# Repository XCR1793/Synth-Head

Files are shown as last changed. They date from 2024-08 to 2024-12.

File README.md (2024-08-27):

# Synth Head
To create an open source suit which can be worn by an individual and customised to their will. It also must be constructed in such a way that an average human could build it within a reasonable budget and time. The suit must be modular whilst remaining safe for the user to operate. The software must be easy to configure for any individual and has capability to modify without the need to always reflashing its firmware. The project was created according to this standard however, it has evolved over time to be more of a testing ground for sensors and other features of the like as I will continue this along with other projects I have due to compatibility.

DX.3

## Overview
This project is always in the works and will be updated. Although regular updates are not possible due to me still being in uni, I will do what I can. This repo is basically a better version of the other repo and a true migration as the old one due to its structure. The reason for it being a new repo rather then just a fix is cause the title changed so the old link wouldn't have worked anyway. The current design is DX which stands for Design 10 as it is the 10th time the base shape has changed, the .3 at the end is an iterator for which version were on.

### Features
* <strong style='color: #99ccff;'>Vacuum Formed Visor</strong> allows the user to see out of a clear shell rather then the previous mesh version which caused chromatic abberation, preventing the true colours of the display from emiting through the visor properly.
* <strong style='color: #99ccff;'>Detachable Substructure</strong> which conformes to the visor ridge provides an easy to modify platform to which different displays, sensors and other modules.
* <strong style='color: #99ccff;'>Builtin Head Restraint</strong> was designed to hold in an average head with relatively high pressure, although the pressure seems like it cause pain, the addition of a foam pad mitigates this and is actually comfortable to wear.
* <strong style='color: #99ccff;'>Silent Slim Jaw Mount</strong> of around 6mm in total thickness is directly integrated to the shell.
* <strong style='color: #99ccff;'>Snoot Sensors</strong> All of the sensors and modules are attached directly into the detachable substructure and can easily be replaced and upgraded as needed, many of which includes: Boop detection, snoot holding detection & IMUs.
* <strong style='color: #99ccff;'>Ventillation</strong> is key to an alive and well user, there are 2 fans located below the tongue which negatively ventillates the user.

### In the works
* The visor edge and mating surface will be changed due to it currently resulting in an uneven edge to edge connection.
* The builtin head restraint will also be upgraded, although the system works it is not the best designed as it is currently difficult to put the pins in place.
* Electronics & other cabling will be hidden in the final release as it is not compact due to the Rushed version built for speed and prototyping rather then stability.
* ARCOS migration is still under play, the entire library is basically being rewritten slowly so it runs faster with more features. The library is currently not accessable as it is privated but it will be released with the release of the synth head 10.3.
* <strong style='color: #ffb3ff;'>Feature Inclusion:</strong> Cable management
* <strong style='color: #ffb3ff;'>Feature Inclusion:</strong> Visor Edge Alignment Upgrade
* <strong style='color: #ffb3ff;'>Feature Inclusion:</strong> Ventillation Upgrade
* <strong style='color: #ffb3ff;'>Feature Inclusion:</strong> Jaw Mount Upgrade (Attached to head restraint)
* <strong style='color: #ffb3ff;'>Feature Inclusion:</strong> Lighter Frame
* <strong style='color: #ffb3ff;'>Feature Inclusion:</strong> Custom PCB (Control Board, Power & Sensors)

### Roadmap
* <strong style='color: #99ff99;'>Milestone:</strong> [Synth Head DX](/Archives/DX/README.md)
* <strong style='color: #99ff99;'>Milestone:</strong> [Synth Head DX.1](/Archives/DX.1/README.md)
* <strong style='color: #99ff99;'>Milestone:</strong> [Synth Head DX.2 Rushed](/Archives/DX.2/README.md)
* <strong style='color: #99ff99;'>Milestone:</strong> [Synth Head DX.3 Rushed](/Archives/DX.3/README.md)
* <strong style='color: #99ff99;'>Milestone:</strong> Properly Structured Github

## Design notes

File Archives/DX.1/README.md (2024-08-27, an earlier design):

# Synth Head DX.1
Building off of the DX base, many more components were added. This version of the DX series was to brainstorm, test and prototype if the shell worked IRL along with with features could be theoretically added. I stayed in this version for a while when developing the physical design and concidering alternative restraint mechanisms. The [manifesto](/README.md#synth-head) when constructing this remained. Although this version does have a physical build to it, <strong style='color: #ff0000;'>IT IS NOT RECOMMENDED</strong> that you construct this without your modifications due to some known design issues.

## Known Issues
* Neck Plate Attachment to head is missing as the plates were an after thought.
* Neck Plate Attachment to each other is also missing as the plates were designed independantly of each other and near the end of the version's use.
* Head Restraint not providing enough pressure was determined after construction as the realisation that there was no tensioning mechanism other then just manually pulling the steel zip tie.
* No way to properly attach the tongue as this was designed during construction.
* Neck Plate Tensioning is lacking as the rubber bands that were used barely had enough strength to prop themselves up.
* Unconfortable Jaw Joint design which was only detected after constructing and during the testing stages.

## File Structure
<strong style='color: #bb99ff;'>XCR Head DX.1.f3d</strong> : A fusion 360 file for the main project where the entirity of DX.1 was designed.

<strong style='color: #bb99ff;'>XCR Head DX.1.step</strong> : A step file version incase you dont have fusion 360 to open the main project.

<strong style='color: #bb99ff;'>Rubber Holder V3.step</strong> : A step file of the rubber band holder reference.

<strong style='color: #bb99ff;'>Subsurface Jaw Joint V3.step</strong> : A step file of the jaw joint v3 mechanism.

<strong style='color: #bb99ff;'>Ziptie Release & Back Brace.step</strong> : A step file of the steel cable tie head restraint assembly.

<strong style='color: #bb99ff;'>Visor Mesh.step</strong> : A step file for the Mesh Visor addon incase you cant vacuum form your own visor.

<strong style='color: #bb99ff;'>DX Visor Buck.f3d</strong> : A f3d file for the visor buck to vacuum form.

<strong style='color: #bb99ff;'>DX Visor Buck.step</strong> : A step file for the visor buck to vacuum form incase you dont have fusion 360.

## Features & Design Considerations
### DX
All features from the DX base design are included except the Jaw Joint and a modification to the head restraint.

### Jaw Joint Upgrade
The jaw hinge mechanism was upgraded from V2 to V3 which allows a slimmer mating surface which connects the jaw to the shell. This new version does not require a teflon tube to be inserted to lock the hinge into place, rather it is a press and turn system where the joint is designed to be integrated below the surface of the shell rather then on top. This allows the upgrade to sit more flush within the shell.

### Foam Mount for Head Restraint
As hotglue is not always available to the user, an inset slot was designed to grip the foam on its way in rather than with any other adhesives, preventing the foam from being destroyed due to hotglue and granting the user to easily change it out.

### Steel Cable Tie Head Restraint
As the base design offered no tensioning or size adjustment mechanism, a slidable adjuster was created via leveraging the use of a steel cable tie. Slight modifications to the actual cable tie sliding system was required to allow the cable tie to actually unlock.

### Steel Cable Tie Neck Plate Mounts
The springy ness of the steel cable tie was also experimented here by attaching the neck plates to them which automatically averaged their positions like a spline, which proved incredibly useful as the rubber bands on their own could not do the job.

### Slottable Top Maw Plate
An upgrade to the maw plate also was required however, it still did required the user to tack weld the piece into place as there wasn't any system that prevent it from just popping back out.

### Jaw Rubber Band Tensioning
Using the V3 rubber band mount proved to be a worthy upgrade as it prevented the sharp edges of the previous design from scratching the user during its motion. It is required for the jaw to function as there is no mechanism that prevents the jaw from slacking open.

### TPU Neck Plate Mounts
In addition to the steel cable tie mounts for the neck plates, a tpu version was also tested. This design allowed fixed equal spacing between the scales plates whilst also being flexible enough to bend to the user's movements.

### Mesh Visor Addon
If you dont have access to a vacuum former then fret not, I have also provided a mesh version of the visor which you can 3D print or cut out that should confirm roughly to the shape of the original visor.

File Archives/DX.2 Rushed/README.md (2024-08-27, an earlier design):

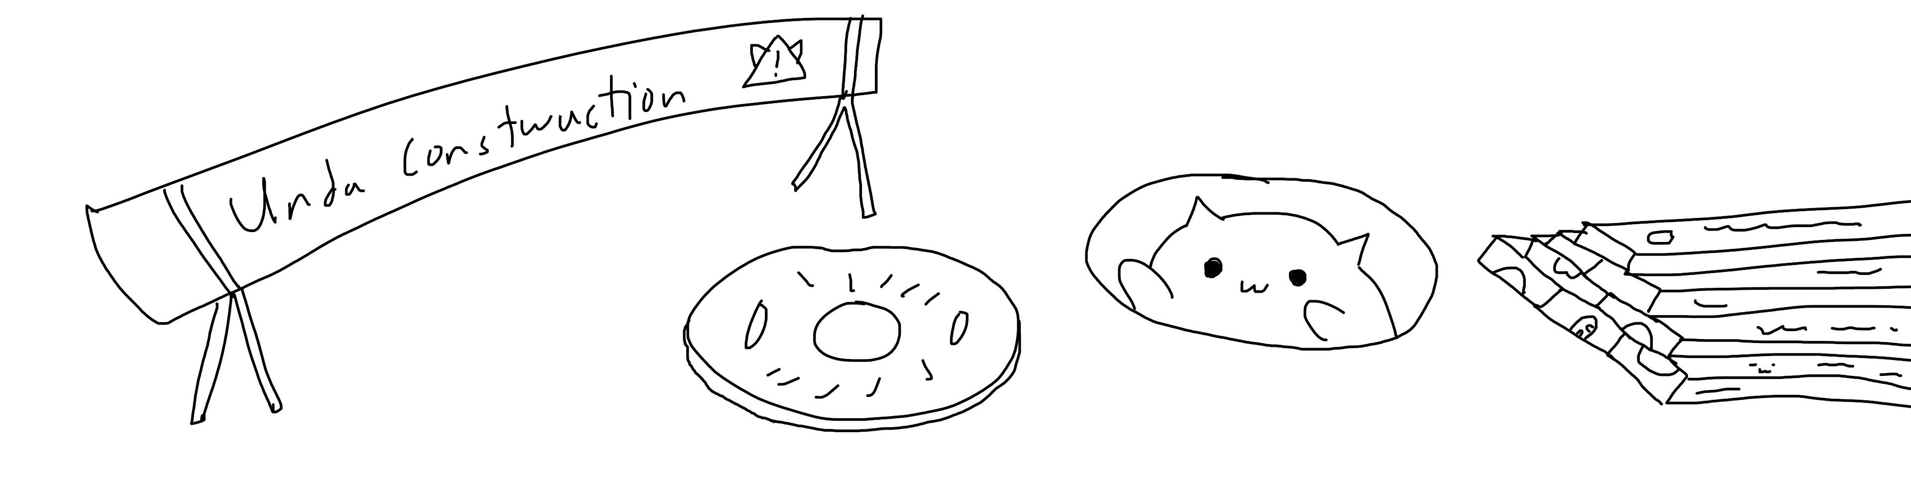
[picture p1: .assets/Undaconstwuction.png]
UnderConstruction


# DX.2 Rushed
Rushed is a modifier that is placed after a project name if I am under a heavy time constraint such as 2-3 weeks to construct one from scratch. 

## Knows Issues

## File Structure
<strong style='color: #bb99ff;'></strong>

## Features & Design Considerations
### <strong style='color: #ff9999;'>Hardware:</strong> DX
All features from the DX base design are included except the Jaw Joint and a modification to the head restraint.

### <strong style='color: #ff9999;'>Hardware:</strong> Large Powerbank Holder
A strong partial case designed to hold a heavy duty powerbank which also doubles as a balancing mechanism to prevent the forward torque caused by unequal weight distrobution of the synth head.

### <strong style='color: #ff9999;'>Hardware:</strong> Head Restraint
The Restraint changed 

### <strong style='color: #ff9999;'>Hardware:</strong> Modified Jaw Joint

### <strong style='color: #ff9999;'>Hardware:</strong> Maw Top Plate Mounting

### <strong style='color: #ff9999;'>Hardware:</strong> Magnetic Visor Mount

### <strong style='color: #ff9999;'>Hardware:</strong> Electronics Mounts

### <strong style='color: #99ff99;'>Electronics:</strong> IR User Detection

### <strong style='color: #99ff99;'>Electronics:</strong> Menu Buttons

### <strong style='color: #99ff99;'>Electronics:</strong> ESP32 Hall Effect

### <strong style='color: #99ff99;'>Electronics:</strong> Dual ESP32

### <strong style='color: #99ff99;'>Electronics:</strong> IMU

### <strong style='color: #99ff99;'>Electronics:</strong> Fan

### <strong style='color: #99ff99;'>Electronics:</strong> HUB75 LED Matrix P3

### <strong style='color: #99ff99;'>Electronics:</strong> LED Strips

### <strong style='color: #99ffff;'>Software:</strong> Boot Screen

### <strong style='color: #99ffff;'>Software:</strong> LED Display

### <strong style='color: #99ffff;'>Software:</strong> Eye Wobble

### <strong style='color: #99ffff;'>Software:</strong> RGB Shader

### <strong style='color: #99ffff;'>Software:</strong> User Detection

### <strong style='color: #99ffff;'>Software:</strong> Visor Detection

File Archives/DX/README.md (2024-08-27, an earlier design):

# Synth Head DX
This is the first the 10th design line up, although the physical architecture is simple it layed the foundation for the other versions to be built on. <strong style='color: #ff0000;'>DO NOT FABRICATE AS IS</strong> as the shape and overall dimentions were the priority when designing this base, this version is more so to be used as an easily modifiable platform which anyone can take and customise. This version has not been created IRL as like mentioned before it was more designed for its shape.

## File Structure
<strong style='color: #bb99ff;'>XCR Head DX.f3d</strong> : The fusion 360 file which has everything that was used for the design.

<strong style='color: #bb99ff;'>XCR Head DX.step</strong> : A step file export from fusion 360 if you dont have the program.

## Features & Design Considerations
### Vacuum Formed Visor
The visor contour is designed in such a way, where the visor can rotate outwards rather then relying on the flexibility of the material to snap in place. This prevents the visor from deforming which allows substructures and other features to reliably attach to the visor material. Although a complex shape, it is relatively easy to vacuum form.

<!-- ![DX Visor](../../.assets/DX%20Visor.png) -->

### Visor Ridge
The visor ridge of the shell was designed to "catch" the visor on the way on so that it will always be inline with the shell to leave a near seamless smooth finish. The design process is very simple, consisting of a few offsets and is proceedurly generated allowing any visor shape to fit in this way.
 
### Teeth Rotation
The teeth of the outer shell are rotated slightly along with the jaw being slightly indented. This shape prevents the jaw and the shell from colliding when it moves.

### Head Restraint
This prevents the user's head from moving within the synth head, although it is only a rudamentory design, it was created to have foam hotglued into place. The front and back pieces along with the side shell, locks the user's head in translational movement. Rotational movement is only restrained via pressure which isn't the best method as it doesnt take advantage of the oval shape of the human head, which can be used to geometrically lock the rotation properly like a bike helmet.

### Jaw Joint
The joint mechanism used here was the most tested version at that time which consists of a slot which the jaw can lock into via a teflon pin. This was later depreciated for a better design which allowed the jaw to lock into place via pressing it in and rotating it.

### Maw Top Plate
To mount components such as the display, a top plate was added to do just that. This version just showed whether or not such a design would be aesthetically pleasing along with physically advantages.

### Nose Holes
Holes in the shell served 2 purposes, the first is for it to be accurate to the species however the second reason was for ventillation. Although it doesn't do much, it was design to be enough for air to circulate outwards and the visor to not fog up.

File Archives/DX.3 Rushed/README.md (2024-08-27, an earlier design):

UnderConstruction

# DX.3 Rushed

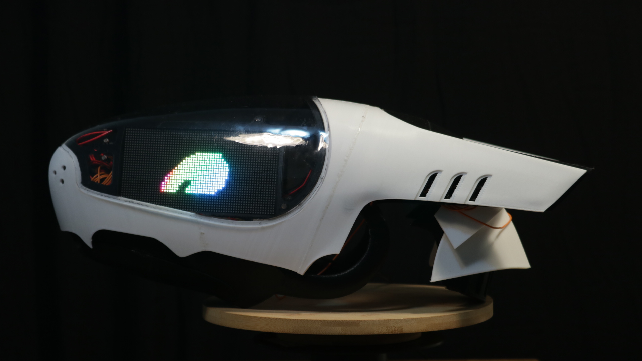
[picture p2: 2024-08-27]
.assets/DX.3 Rushed Side.JPG

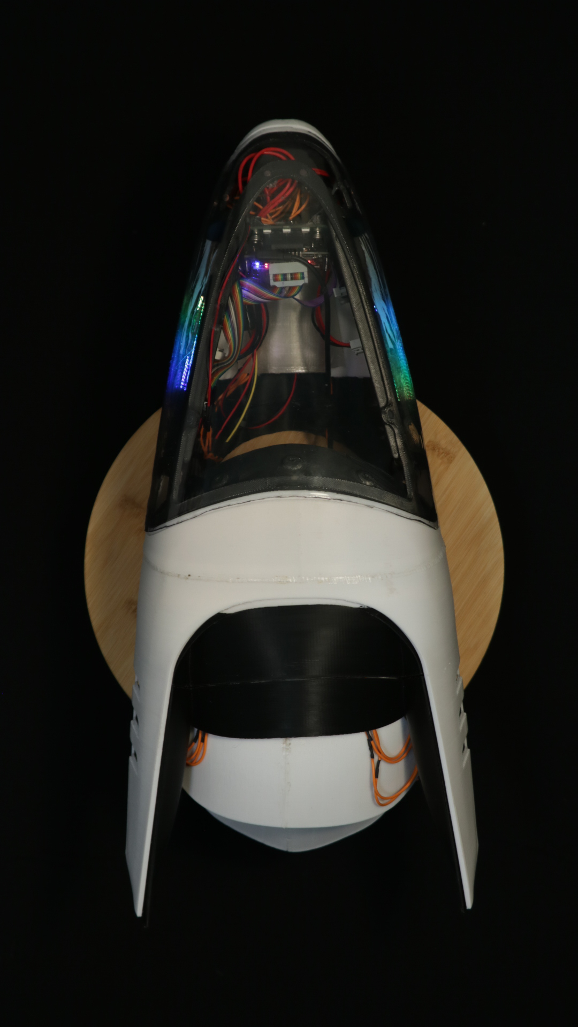
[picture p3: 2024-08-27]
.assets/DX.3 Rushed Top.JPG

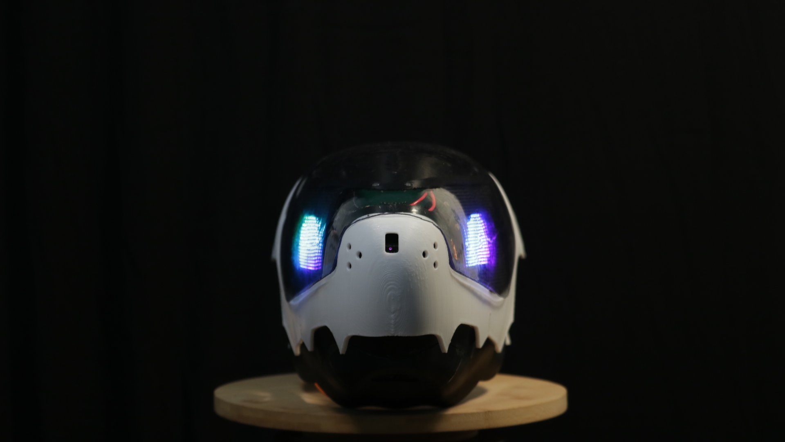
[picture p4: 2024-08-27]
.assets/DX.3 Rushed Front.JPG

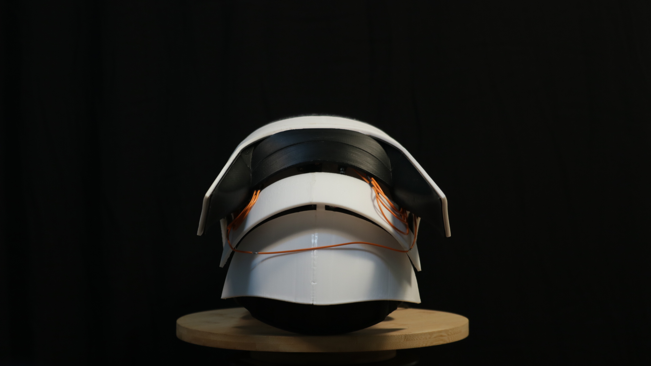
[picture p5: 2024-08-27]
.assets/DX.3 Rushed Back.JPG

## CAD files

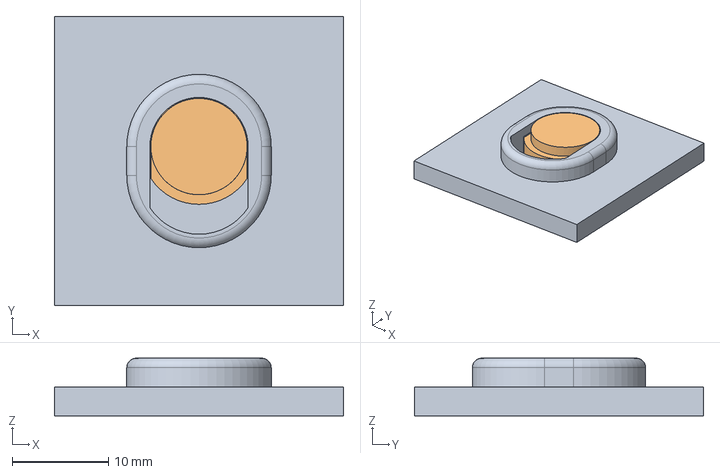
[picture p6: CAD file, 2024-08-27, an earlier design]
Archives/DX.1/Subsurface Jaw Joint V3.step
30.0 x 30.0 x 6.00 mm

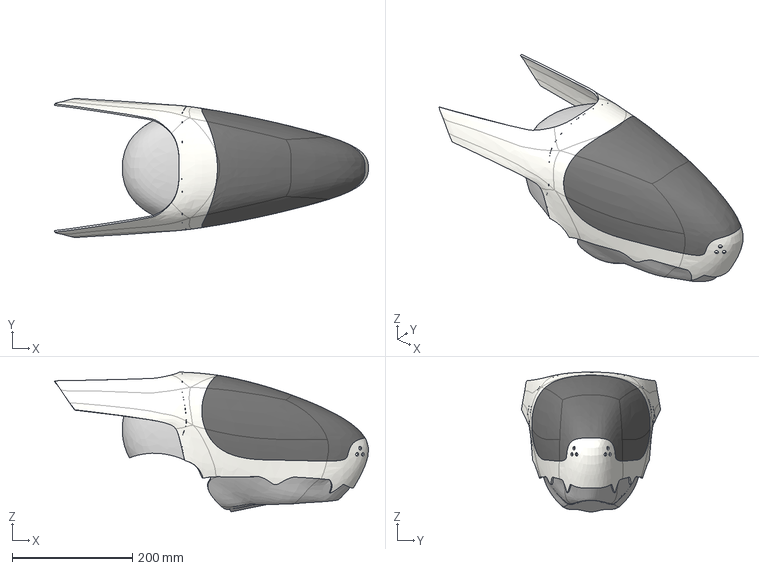
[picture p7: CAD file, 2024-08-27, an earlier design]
Archives/DX/XCR Head DX.step
522.6 x 231.6 x 232.7 mm

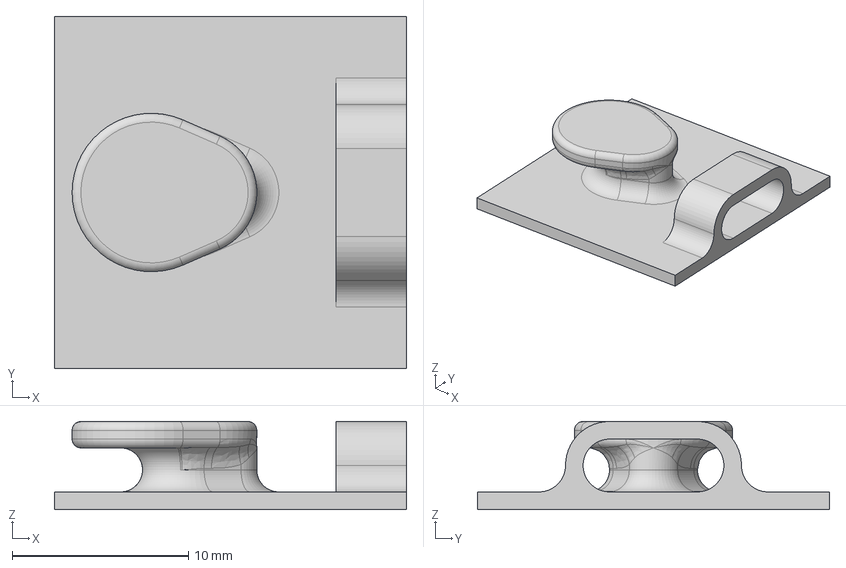
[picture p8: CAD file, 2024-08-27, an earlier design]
Archives/DX.1/Rubber Holder V3.step
20.0 x 20.0 x 5.00 mm

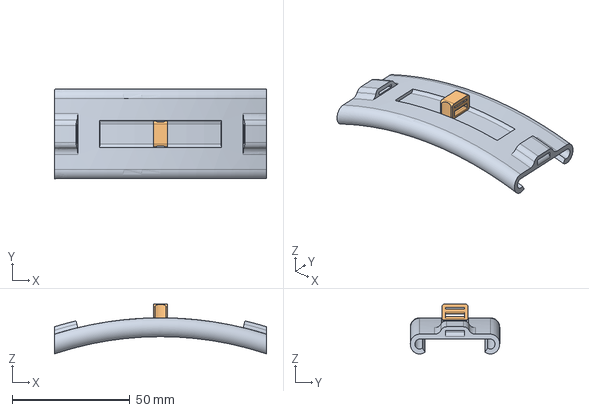
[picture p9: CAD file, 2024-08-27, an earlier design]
Archives/DX.1/Ziptie Release & Back Brace.step
90.0 x 38.0 x 21.2 mm

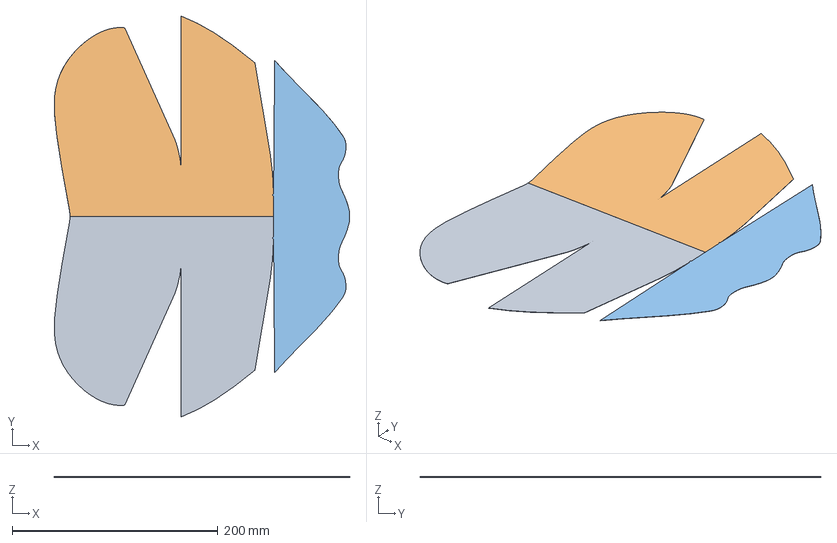
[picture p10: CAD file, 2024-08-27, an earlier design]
Archives/DX.1/Visor Mesh.step
287.4 x 390.0 x 0.2 mm

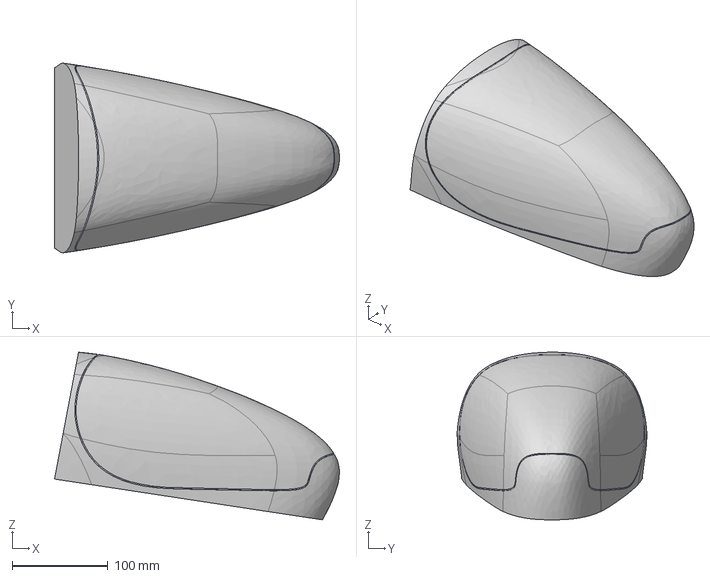
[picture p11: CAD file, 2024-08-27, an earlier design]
Archives/DX.1/DX Visor Buck.step
298.2 x 198.6 x 175.5 mm

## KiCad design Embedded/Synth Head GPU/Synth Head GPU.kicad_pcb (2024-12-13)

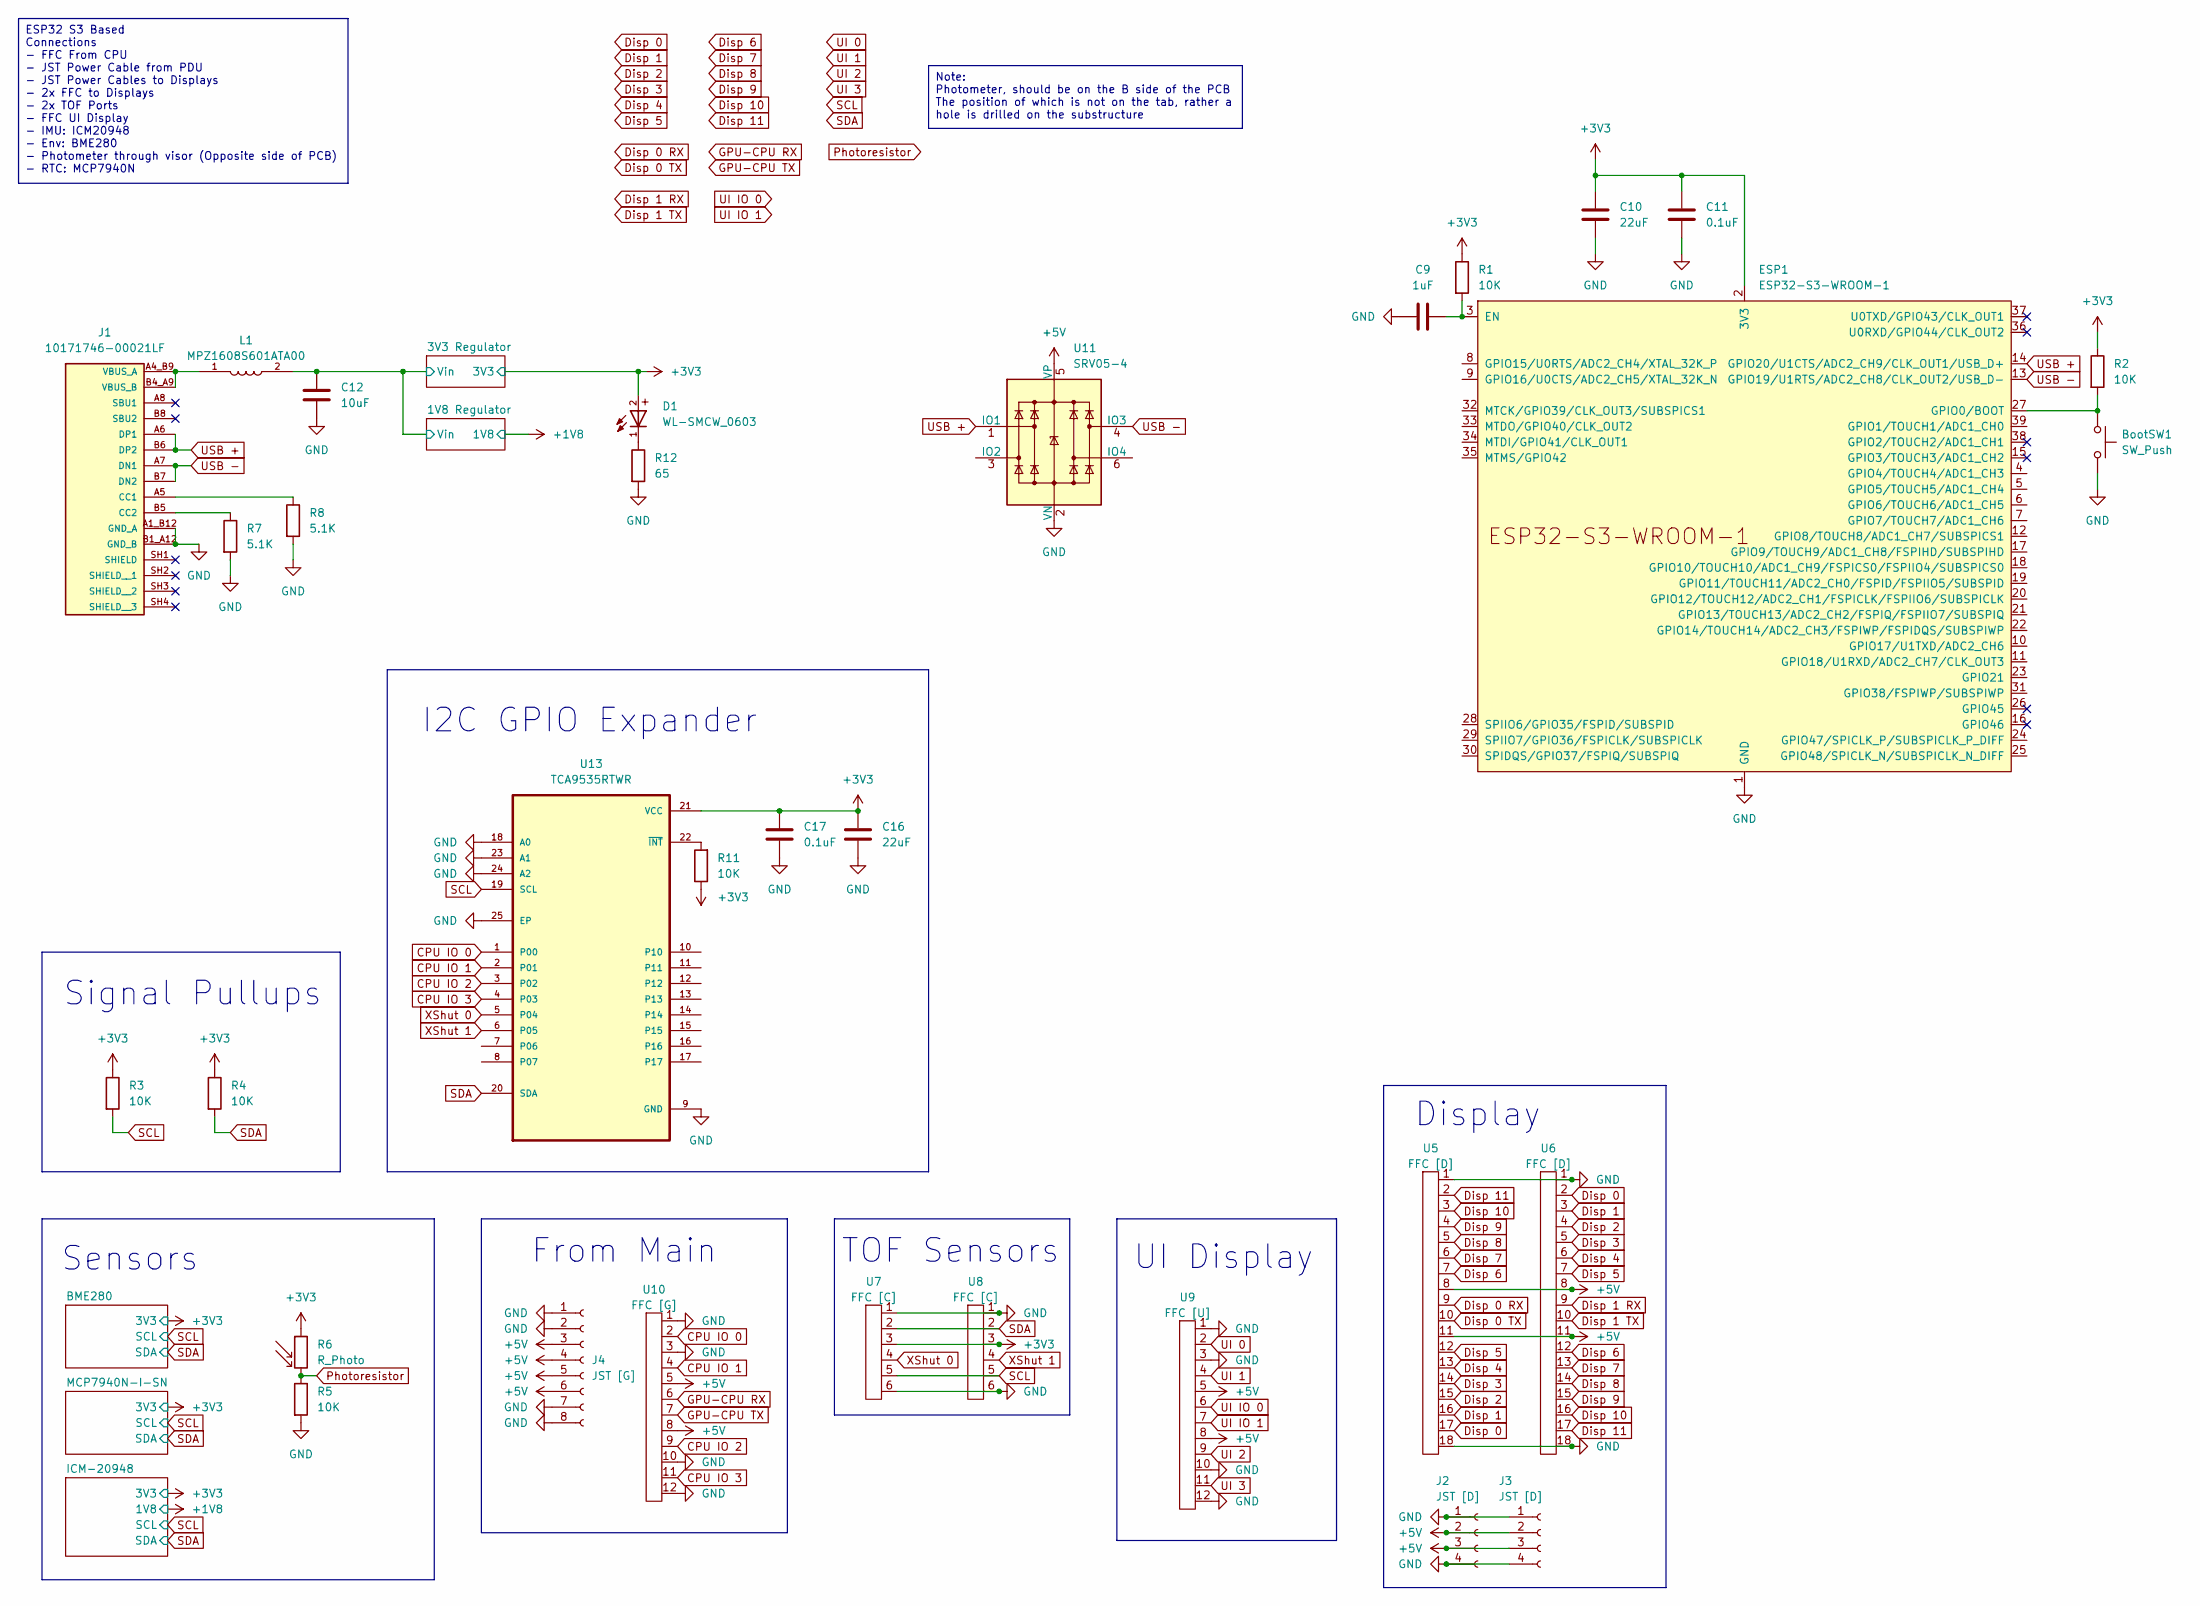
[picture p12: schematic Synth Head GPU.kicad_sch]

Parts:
BootSW1: SW_Push; Button-R-667843
C9: 1uF; C_0603_1608Metric
C10, C16: 22uF; C_0603_1608Metric_Pad1.08x0.95mm_HandSolder
C11, C17: 0.1uF; C_0603_1608Metric
C12: 10uF; C_0603_1608Metric
D1: WL-SMCW_0603
ESP1: ESP32-S3-WROOM-1; ESP32-S3-WROOM-1U
J1: 10171746-00021LF; AMPHENOL_10171746-00021LF; PARTREV A
J2, J3: JST [D]; Molex_PicoBlade_53048-0410_1x04_P1.25mm_Horizontal
J4: JST [G]; PinHeader_1x08_P2.54mm_Horizontal
L1: MPZ1608S601ATA00; INDC1608X95N
R1, R2, R11: 10K; R_0603_1608Metric
R3, R4, R5: 10K; R_0603_1608Metric_Pad0.98x0.95mm_HandSolder
R6: R_Photo; Photoresistor Aliexpress
R7, R8: 5.1K; R_0603_1608Metric
R12: 65; R_0603_1608Metric_Pad0.98x0.95mm_HandSolder
U5, U6: FFC [D]; FFC Aliexpress 0.5mm 18P
U7, U8: FFC [C]; FFC Aliexpress 0.5mm 6P
U9: FFC [U]; FFC Aliexpress 0.5mm 12P
U10: FFC [G]; FFC Aliexpress 0.5mm 12P
U11: SRV05-4; SOT-23-6
U13: TCA9535RTWR; QFN50P400X400X80-25N

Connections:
+3V3: C10.1, C11.1, C16.1, C17.1, D1.2, ESP1.2 (3V3), R1.1, R2.1, R3.1, R4.1, R6.1, R11.1, U7.3, U8.3, U13.21 (VCC); also elsewhere on the board
CPU IO 0: U10.2, U13.1 (P00)
CPU IO 1: U10.4, U13.2 (P01)
CPU IO 2: U10.9, U13.3 (P02)
CPU IO 3: U10.11, U13.4 (P03)
Disp 0: U5.17, U6.2
Disp 0 RX: U5.9
Disp 0 TX: U5.10
Disp 1: U5.16, U6.3
Disp 1 RX: U6.9
Disp 1 TX: U6.10
Disp 2: U5.15, U6.4
Disp 3: U5.14, U6.5
Disp 4: U5.13, U6.6
Disp 5: U5.12, U6.7
Disp 6: U5.7, U6.12
Disp 7: U5.6, U6.13
Disp 8: U5.5, U6.14
Disp 9: U5.4, U6.15
Disp 10: U5.3, U6.16
Disp 11: U5.2, U6.17
GND: BootSW1.2, C9.1, C10.2, C11.2, C12.2, C16.2, C17.2, ESP1.1 (GND), ESP1.40 (GND), ESP1.41 (GND), J1.A1_B12 (GND_A), J1.B1_A12 (GND_B), J2.1, J2.4, J3.1, J3.4, J4.1, J4.2, J4.7, J4.8, R5.2, R7.2, R8.2, R12.2, U5.1, U5.18, U6.1, U6.18, U7.1, U7.6, U8.1, U8.6, U9.1, U9.3, U9.10, U9.12, U10.1, U10.3, U10.10, U10.12, U11.2 (VN), U13.9 (GND), U13.18 (A0), U13.23 (A1), U13.24 (A2), U13.25 (EP); also elsewhere on the board
GPU-CPU RX: U10.6
GPU-CPU TX: U10.7
unnamed: D1.1, R12.1
unnamed: C9.2, ESP1.3 (EN), R1.2
unnamed: BootSW1.1, ESP1.27 (GPIO0/BOOT), R2.2
unnamed: J1.A5 (CC1), R8.1
unnamed: J1.B5 (CC2), R7.1
unnamed: R11.2, U13.22 (~INT)
Photoresistor: R5.1, R6.2
SCL: R3.2, U7.5, U8.5, U13.19 (SCL); also elsewhere on the board
SDA: R4.2, U7.2, U8.2, U13.20 (SDA); also elsewhere on the board
UI 0: U9.2
UI 1: U9.4
UI 2: U9.9
UI 3: U9.11
UI IO 0: U9.6
UI IO 1: U9.7
USB +: ESP1.14 (GPIO20/U1CTS/ADC2_CH9/CLK_OUT1/USB_D+), J1.A6 (DP1), J1.B6 (DP2), U11.1 (IO1)
USB -: ESP1.13 (GPIO19/U1RTS/ADC2_CH8/CLK_OUT2/USB_D-), J1.A7 (DN1), J1.B7 (DN2), U11.4 (IO3)
XShut 0: U7.4, U13.5 (P04)
XShut 1: U8.4, U13.6 (P05)

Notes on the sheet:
ESP32 S3 Based Connections - FFC From CPU - JST Power Cable from PDU - JST Power Cables to Displays - 2x FFC to Displays - 2x TOF Ports - FFC UI Display - IMU: ICM20948 - Env: BME280 - Photometer through visor (Opposite side of PCB) - RTC: MCP7940N
Note: Photometer, should be on the B side of the PCB The position of which is not on the tab, rather a hole is drilled on the substructure
Signal Pullups
I2C GPIO Expander
TOF Sensors
From Main
Display
UI Display
Sensors

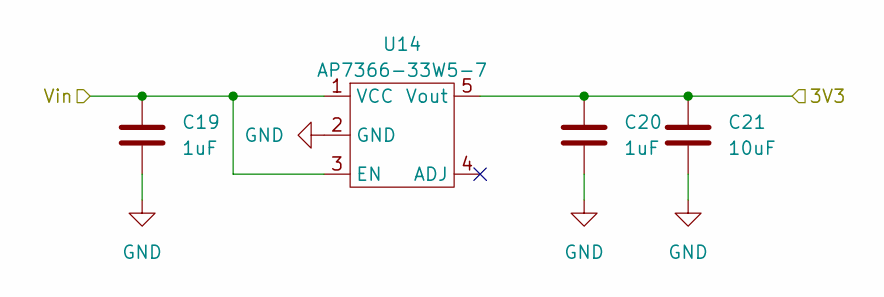
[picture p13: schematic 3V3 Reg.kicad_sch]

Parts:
C19, C20: 1uF; R_0603_1608Metric
C21: 10uF; C_0603_1608Metric
U14: AP7366-33W5-7; AP7366

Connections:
+3V3: C20.1, C21.1, U14.5 (Vout); also elsewhere on the board
GND: C19.2, C20.2, C21.2, U14.2 (GND); also elsewhere on the board

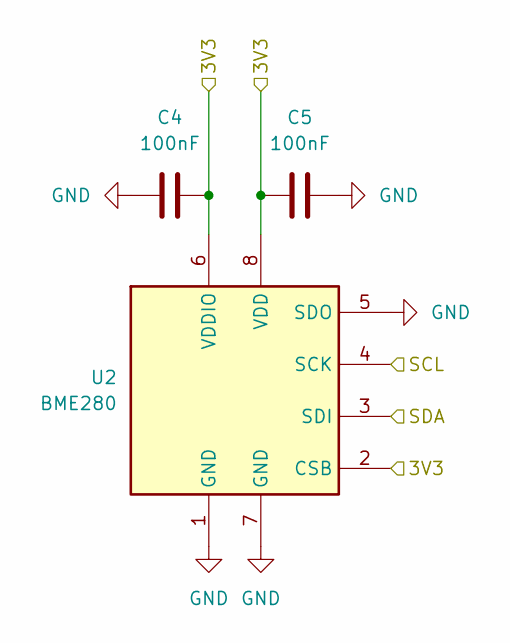
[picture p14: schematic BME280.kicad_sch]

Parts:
C4, C5: 100nF; C_0603_1608Metric_Pad1.08x0.95mm_HandSolder
U2: BME280; Bosch_LGA-8_2.5x2.5mm_P0.65mm_ClockwisePinNumbering

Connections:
+3V3: C4.2, C5.1, U2.2 (CSB), U2.6 (VDDIO), U2.8 (VDD); also elsewhere on the board
GND: C4.1, C5.2, U2.1 (GND), U2.5 (SDO), U2.7 (GND); also elsewhere on the board
SCL: U2.4 (SCK); also elsewhere on the board
SDA: U2.3 (SDI); also elsewhere on the board

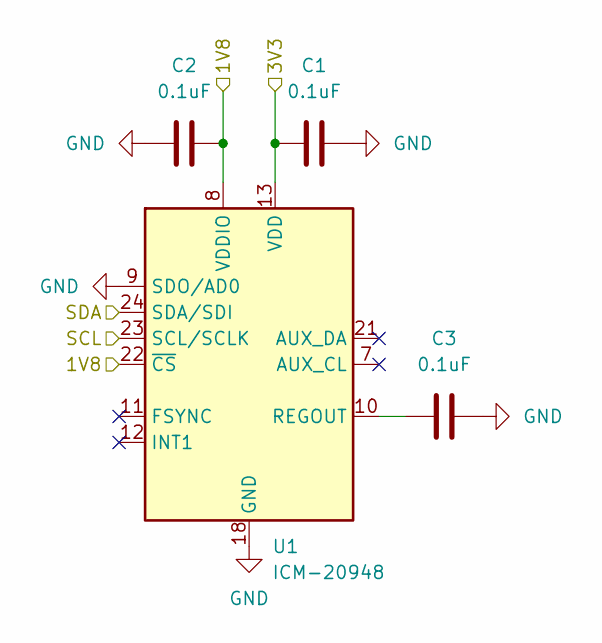
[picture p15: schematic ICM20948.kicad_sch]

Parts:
C1, C2, C3: 0.1uF; C_0603_1608Metric_Pad1.08x0.95mm_HandSolder
U1: ICM-20948; InvenSense_QFN-24_3x3mm_P0.4mm

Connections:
+1V8: C2.2, U1.8 (VDDIO), U1.22 (~CS); also elsewhere on the board
+3V3: C1.1, U1.13 (VDD); also elsewhere on the board
GND: C1.2, C2.1, C3.2, U1.9 (SDO/AD0), U1.18 (GND), U1.20 (GND); also elsewhere on the board
unnamed: C3.1, U1.10 (REGOUT)
SCL: U1.23 (SCL/SCLK); also elsewhere on the board
SDA: U1.24 (SDA/SDI); also elsewhere on the board

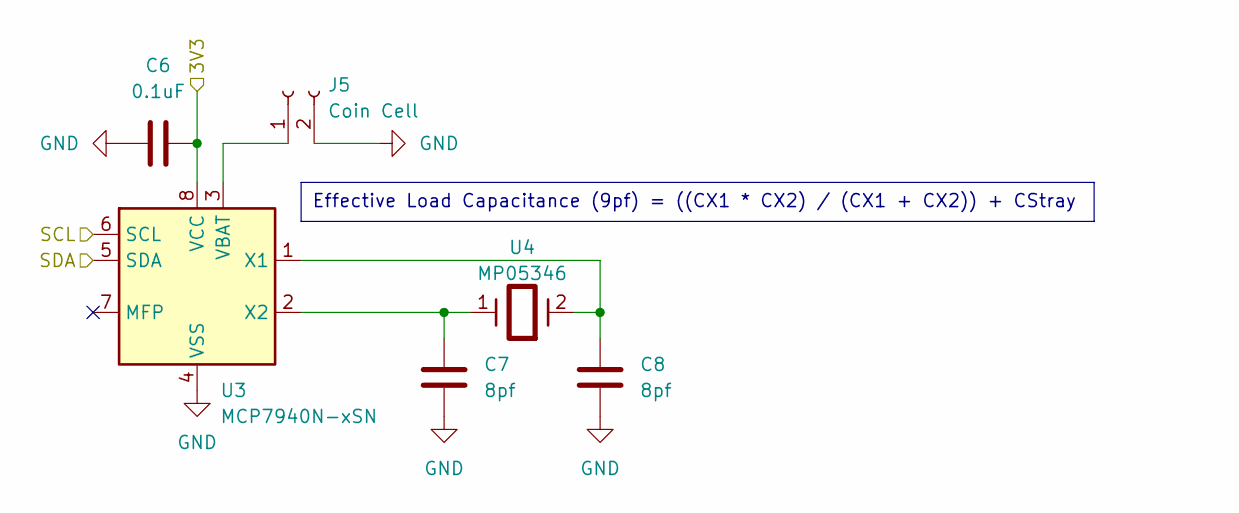
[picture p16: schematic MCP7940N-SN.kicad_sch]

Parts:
C6: 0.1uF; C_0603_1608Metric_Pad1.08x0.95mm_HandSolder
C7, C8: 8pf; C_0603_1608Metric_Pad1.08x0.95mm_HandSolder
J5: Coin Cell; PinHeader_1x02_P2.54mm_Vertical
U3: MCP7940N-xSN; SOIC-8_3.9x4.9mm_P1.27mm
U4: MP05346

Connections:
+3V3: C6.2, U3.8 (VCC); also elsewhere on the board
GND: C6.1, C7.2, C8.2, J5.2, U3.4 (VSS); also elsewhere on the board
unnamed: J5.1, U3.3 (VBAT)
unnamed: C8.1, U3.1 (X1), U4.2
unnamed: C7.1, U3.2 (X2), U4.1
SCL: U3.6 (SCL); also elsewhere on the board
SDA: U3.5 (SDA); also elsewhere on the board

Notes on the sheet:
Effective Load Capacitance (9pf) = ((CX1 * CX2) / (CX1 + CX2)) + CStray

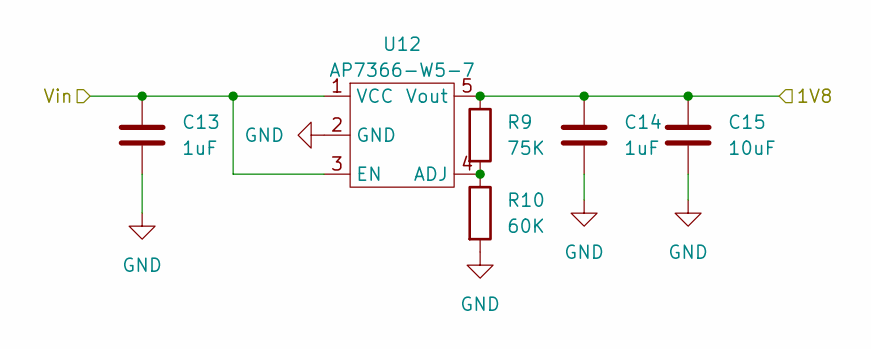
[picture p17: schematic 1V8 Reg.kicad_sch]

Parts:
C13, C14: 1uF; R_0603_1608Metric
C15: 10uF; C_0603_1608Metric
R9: 75K; R_0603_1608Metric
R10: 60K; R_0603_1608Metric
U12: AP7366-W5-7; AP7366

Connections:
+1V8: C14.1, C15.1, R9.1, U12.5 (Vout); also elsewhere on the board
GND: C13.2, C14.2, C15.2, R10.2, U12.2 (GND); also elsewhere on the board
unnamed: R9.2, R10.1, U12.4 (ADJ)

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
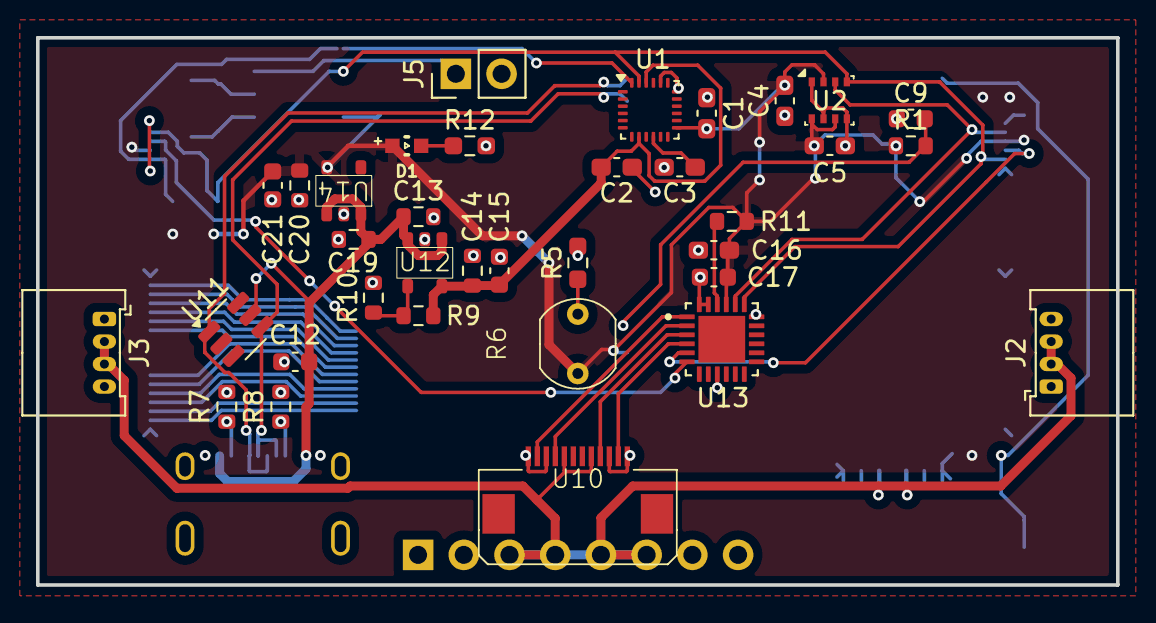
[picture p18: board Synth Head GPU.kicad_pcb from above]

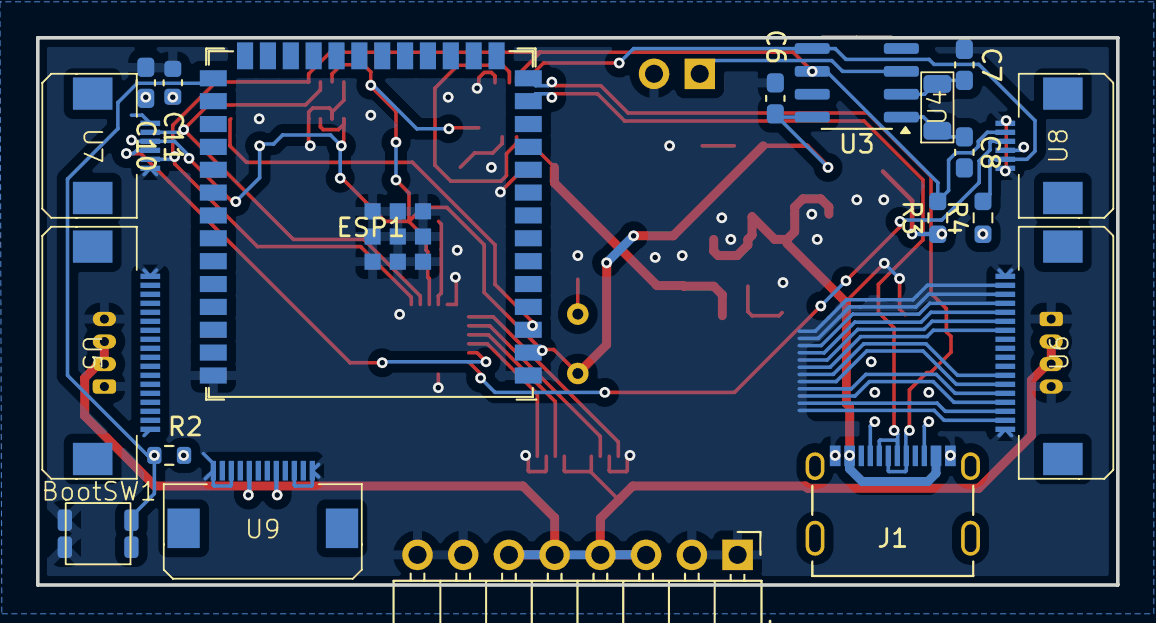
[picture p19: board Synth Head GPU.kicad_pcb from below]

Board: 2 copper layers, 60.0 x 30.4 mm, 54 parts (19 on the bottom side), 38 nets.

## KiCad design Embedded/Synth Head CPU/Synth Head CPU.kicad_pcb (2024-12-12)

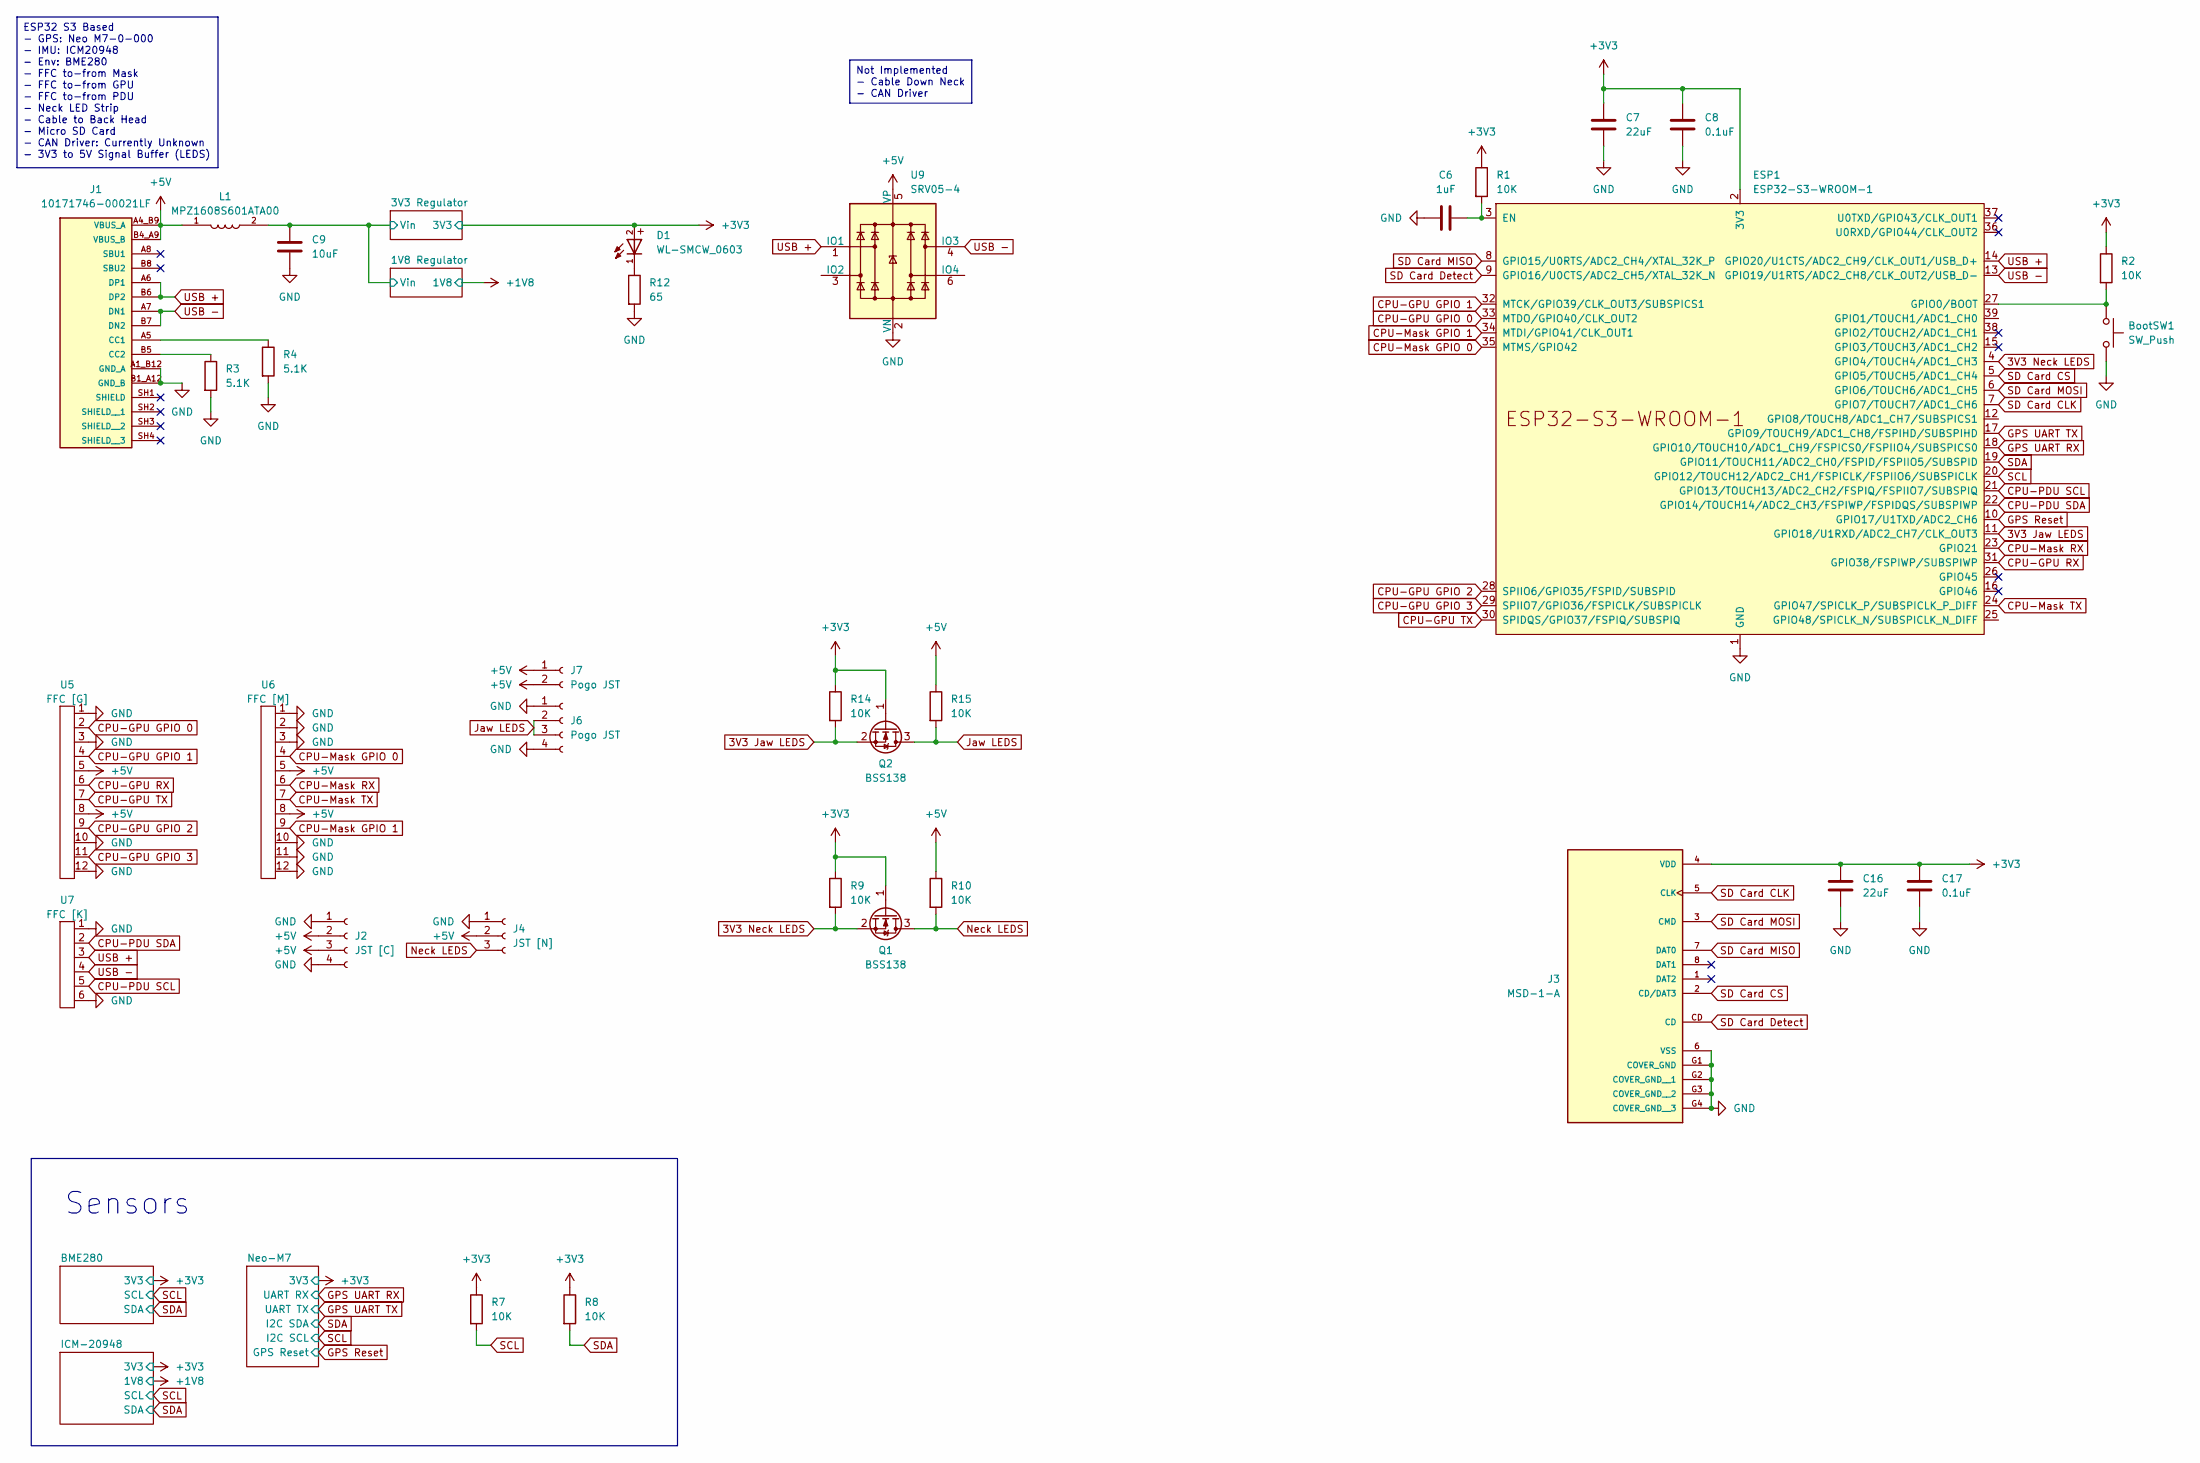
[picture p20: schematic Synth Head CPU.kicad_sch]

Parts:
BootSW1: SW_Push; Button-R-667843
C6: 1uF; C_0603_1608Metric
C7, C16: 22uF; C_0603_1608Metric_Pad1.08x0.95mm_HandSolder
C8, C17: 0.1uF; C_0603_1608Metric_Pad1.08x0.95mm_HandSolder
C9: 10uF; C_0603_1608Metric
D1: WL-SMCW_0603
ESP1: ESP32-S3-WROOM-1
J1: 10171746-00021LF; AMPHENOL_10171746-00021LF; PARTREV A
J2: JST [C]; Molex_PicoBlade_53048-0410_1x04_P1.25mm_Horizontal
J3: MSD-1-A; CUI_MSD-1-A; PARTREV 1.0
J4: JST [N]; Molex_PicoBlade_53048-0310_1x03_P1.25mm_Horizontal
J6: Pogo JST; Molex_PicoBlade_53048-0410_1x04_P1.25mm_Horizontal
J7: Pogo JST; Molex_PicoBlade_53048-0210_1x02_P1.25mm_Horizontal
L1: MPZ1608S601ATA00; INDC1608X95N
Q1, Q2: BSS138; SOT-23
R1, R2: 10K; R_0603_1608Metric
R3, R4: 5.1K; R_0603_1608Metric
R7, R8, R9, R10, R14, R15: 10K; R_0603_1608Metric_Pad0.98x0.95mm_HandSolder
R12: 65; R_0603_1608Metric_Pad0.98x0.95mm_HandSolder
U5: FFC [G]; FFC Aliexpress 0.5mm 12P
U6: FFC [M]; FFC Aliexpress 0.5mm 12P
U7: FFC [K]; FFC Aliexpress 0.5mm 6P
U9: SRV05-4; SOT-23-6

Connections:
3V3 Jaw LEDS: ESP1.11 (GPIO18/U1RXD/ADC2_CH7/CLK_OUT3), Q2.2 (S), R14.2
3V3 Neck LEDS: ESP1.4 (GPIO4/TOUCH4/ADC1_CH3), Q1.2 (S), R9.2
+3V3: C7.1, C8.1, C16.1, C17.1, D1.2, ESP1.2 (3V3), J3.4 (VDD), Q1.1 (G), Q2.1 (G), R1.1, R2.1, R7.1, R8.1, R9.1, R14.1; also elsewhere on the board
+5V: J1.A4_B9 (VBUS_A), J1.B4_A9 (VBUS_B), J2.2, J2.3, J4.2, J7.1, J7.2, L1.1, R10.1, R15.1, U5.5, U5.8, U6.5, U6.8, U9.5 (VP)
/1V8 Regulator/Vin: C9.1, L1.2; also elsewhere on the board
CPU-GPU GPIO 0: ESP1.33 (MTDO/GPIO40/CLK_OUT2), U5.2
CPU-GPU GPIO 1: ESP1.32 (MTCK/GPIO39/CLK_OUT3/SUBSPICS1), U5.4
CPU-GPU GPIO 2: ESP1.28 (SPIIO6/GPIO35/FSPID/SUBSPID), U5.9
CPU-GPU GPIO 3: ESP1.29 (SPIIO7/GPIO36/FSPICLK/SUBSPICLK), U5.11
CPU-GPU RX: ESP1.31 (GPIO38/FSPIWP/SUBSPIWP), U5.6
CPU-GPU TX: ESP1.30 (SPIDQS/GPIO37/FSPIQ/SUBSPIQ), U5.7
CPU-Mask GPIO 0: ESP1.35 (MTMS/GPIO42), U6.4
CPU-Mask GPIO 1: ESP1.34 (MTDI/GPIO41/CLK_OUT1), U6.9
CPU-Mask RX: ESP1.23 (GPIO21), U6.6
CPU-Mask TX: ESP1.24 (GPIO47/SPICLK_P/SUBSPICLK_P_DIFF), U6.7
CPU-PDU SCL: ESP1.21 (GPIO13/TOUCH13/ADC2_CH2/FSPIQ/FSPIIO7/S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), U7.5
CPU-PDU SDA: ESP1.22 (GPIO14/TOUCH14/ADC2_CH3/FSPIWP/FSPIDQS/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), U7.2
GND: BootSW1.2, C6.1, C7.2, C8.2, C9.2, C16.2, C17.2, ESP1.1 (GND), ESP1.40 (GND), ESP1.41 (GND), J1.A1_B12 (GND_A), J1.B1_A12 (GND_B), J2.1, J2.4, J3.6 (VSS), J3.G1 (COVER_GND), J3.G2 (COVER_GND__1), J3.G3 (COVER_GND__2), J3.G4 (COVER_GND__3), J4.1, J6.1, J6.4, R3.2, R4.2, R12.2, U5.1, U5.3, U5.10, U5.12, U6.1, U6.2, U6.3, U6.10, U6.11, U6.12, U7.1, U7.6, U9.2 (VN); also elsewhere on the board
GPS Reset: ESP1.10 (GPIO17/U1TXD/ADC2_CH6); also elsewhere on the board
GPS UART RX: ESP1.18 (GPIO10/TOUCH10/ADC1_CH9/FSPICS0/FSPIIO4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); also elsewhere on the board
GPS UART TX: ESP1.17 (GPIO9/TOUCH9/ADC1_CH8/FSPIHD/SUBSPIHD); also elsewhere on the board
Jaw LEDS: J6.2, J6.3, Q2.3 (D), R15.2
Neck LEDS: J4.3, Q1.3 (D), R10.2
unnamed: D1.1, R12.1
unnamed: C6.2, ESP1.3 (EN), R1.2
unnamed: BootSW1.1, ESP1.27 (GPIO0/BOOT), R2.2
unnamed: J1.A5 (CC1), R4.1
unnamed: J1.B5 (CC2), R3.1
SCL: ESP1.20 (GPIO12/TOUCH12/ADC2_CH1/FSPICLK/FSPIIO6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), R7.2; also elsewhere on the board
SD Card CLK: ESP1.7 (GPIO7/TOUCH7/ADC1_CH6), J3.5 (CLK)
SD Card CS: ESP1.5 (GPIO5/TOUCH5/ADC1_CH4), J3.2 (CD/DAT3)
SD Card Detect: ESP1.9 (GPIO16/U0CTS/ADC2_CH5/XTAL_32K_N), J3.CD
SD Card MISO: ESP1.8 (GPIO15/U0RTS/ADC2_CH4/XTAL_32K_P), J3.7 (DAT0)
SD Card MOSI: ESP1.6 (GPIO6/TOUCH6/ADC1_CH5), J3.3 (CMD)
SDA: ESP1.19 (GPIO11/TOUCH11/ADC2_CH0/FSPID/FSPIIO5/S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), R8.2; also elsewhere on the board
USB +: ESP1.14 (GPIO20/U1CTS/ADC2_CH9/CLK_OUT1/USB_D+), J1.A6 (DP1), J1.B6 (DP2), U7.3, U9.1 (IO1)
USB -: ESP1.13 (GPIO19/U1RTS/ADC2_CH8/CLK_OUT2/USB_D-), J1.A7 (DN1), J1.B7 (DN2), U7.4, U9.4 (IO3)

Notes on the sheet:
Not Implemented - Cable Down Neck - CAN Driver
ESP32 S3 Based - GPS: Neo M7-0-000 - IMU: ICM20948 - Env: BME280 - FFC to-from Mask - FFC to-from GPU - FFC to-from PDU - Neck LED Strip - Cable to Back Head - Micro SD Card - CAN Driver: Currently Unknown - 3V3 to 5V Signal Buffer (LEDS)
Sensors

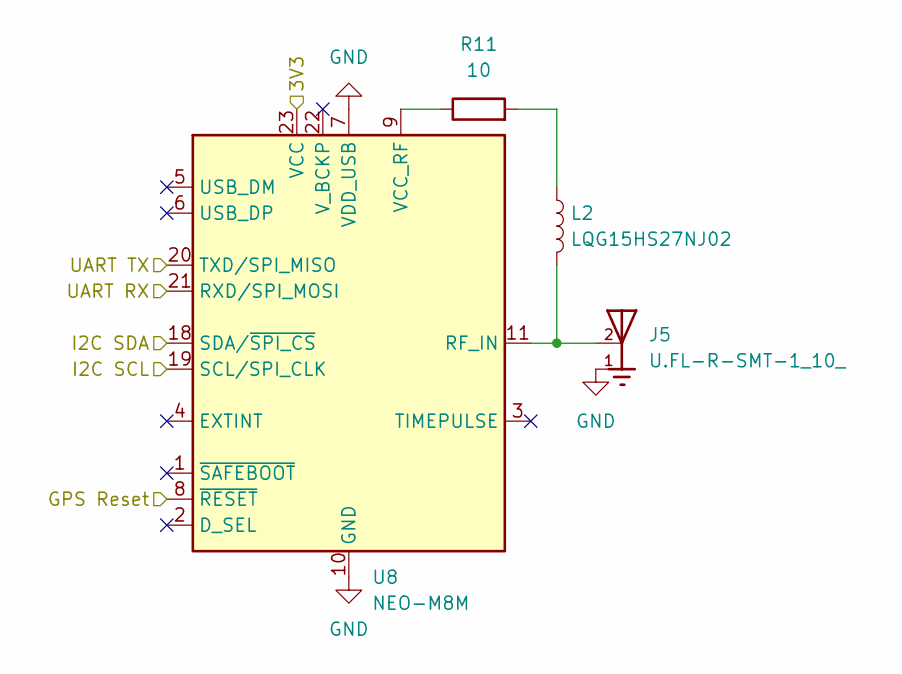
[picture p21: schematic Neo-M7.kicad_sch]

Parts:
J5: U.FL-R-SMT-1_10_; HRS_U.FL-R-SMT-1_10_
L2: LQG15HS27NJ02; L_0402_1005Metric_Pad0.77x0.64mm_HandSolder
R11: 10; C_0603_1608Metric_Pad1.08x0.95mm_HandSolder
U8: NEO-M8M; ublox_NEO

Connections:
+3V3: U8.23 (VCC); also elsewhere on the board
GND: J5.1, U8.7 (VDD_USB), U8.10 (GND), U8.12 (GND), U8.13 (GND), U8.24 (GND); also elsewhere on the board
GPS Reset: U8.8 (~RESET); also elsewhere on the board
GPS UART RX: U8.21 (RXD/SPI_MOSI); also elsewhere on the board
GPS UART TX: U8.20 (TXD/SPI_MISO); also elsewhere on the board
unnamed: L2.1, R11.2
unnamed: J5.2, L2.2, U8.11 (RF_IN)
unnamed: R11.1, U8.9 (VCC_RF)
SCL: U8.19 (SCL/SPI_CLK); also elsewhere on the board
SDA: U8.18 (SDA/~SPI_CS); also elsewhere on the board

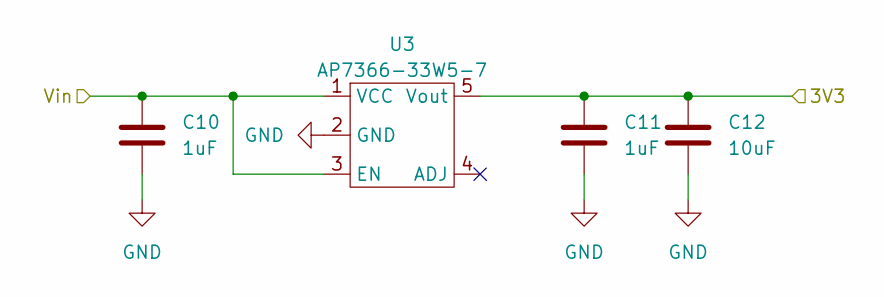
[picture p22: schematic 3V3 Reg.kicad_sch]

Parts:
C10, C11: 1uF; R_0603_1608Metric
C12: 10uF; C_0603_1608Metric
U3: AP7366-33W5-7; AP7366

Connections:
+3V3: C11.1, C12.1, U3.5 (Vout); also elsewhere on the board
/1V8 Regulator/Vin: C10.1, U3.1 (VCC), U3.3 (EN); also elsewhere on the board
GND: C10.2, C11.2, C12.2, U3.2 (GND); also elsewhere on the board

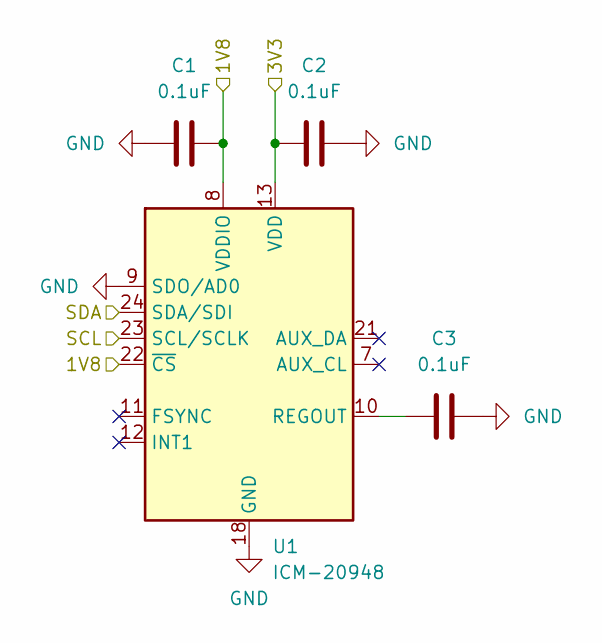
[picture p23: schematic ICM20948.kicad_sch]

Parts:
C1, C2, C3: 0.1uF; C_0603_1608Metric_Pad1.08x0.95mm_HandSolder
U1: ICM-20948; InvenSense_QFN-24_3x3mm_P0.4mm

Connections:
+1V8: C1.2, U1.8 (VDDIO), U1.22 (~CS); also elsewhere on the board
+3V3: C2.1, U1.13 (VDD); also elsewhere on the board
GND: C1.1, C2.2, C3.2, U1.9 (SDO/AD0), U1.18 (GND), U1.20 (GND); also elsewhere on the board
unnamed: C3.1, U1.10 (REGOUT)
SCL: U1.23 (SCL/SCLK); also elsewhere on the board
SDA: U1.24 (SDA/SDI); also elsewhere on the board


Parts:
C13, C14: 1uF; R_0603_1608Metric
C15: 10uF; C_0603_1608Metric
R5: 75K; R_0603_1608Metric
R6: 60K; R_0603_1608Metric
U4: AP7366-W5-7; AP7366

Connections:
+1V8: C14.1, C15.1, R5.1, U4.5 (Vout); also elsewhere on the board
/1V8 Regulator/Vin: C13.1, U4.1 (VCC), U4.3 (EN); also elsewhere on the board
GND: C13.2, C14.2, C15.2, R6.2, U4.2 (GND); also elsewhere on the board
unnamed: R5.2, R6.1, U4.4 (ADJ)


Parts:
C4, C5: 100nF; C_0603_1608Metric_Pad1.08x0.95mm_HandSolder
U2: BME280; Bosch_LGA-8_2.5x2.5mm_P0.65mm_ClockwisePinNumbering

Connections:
+3V3: C4.2, C5.1, U2.2 (CSB), U2.6 (VDDIO), U2.8 (VDD); also elsewhere on the board
GND: C4.1, C5.2, U2.1 (GND), U2.5 (SDO), U2.7 (GND); also elsewhere on the board
SCL: U2.4 (SCK); also elsewhere on the board
SDA: U2.3 (SDI); also elsewhere on the board



Board: 2 copper layers, 60.0 x 35.0 mm, 54 parts (3 on the bottom side), 43 nets.

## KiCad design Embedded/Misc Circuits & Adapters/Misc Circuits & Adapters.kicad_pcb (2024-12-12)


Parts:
J1: VL53L0X; PinHeader_1x06_P2.54mm_Vertical
J2: JST [D]; Molex_PicoBlade_53048-0410_1x04_P1.25mm_Horizontal
J3: HUB75 PWR; Molex_KK-396_A-41791-0004_1x04_P3.96mm_Vertical
J4: 2.0 IPS Display; PinHeader_1x08_P2.54mm_Vertical
J5, J6: I2C OLED; PinHeader_1x04_P2.54mm_Vertical
J7, J8: SPI OLED; PinHeader_1x07_P2.54mm_Vertical
J9: HUB75; PinHeader_2x08_P2.54mm_Vertical
J10: JST [S]; Molex_PicoBlade_53047-0810_1x08_P1.25mm_Vertical
J11: Pogo Pins; 2.2mm 20P
J12: Jaw Pogo Cable; PinHeader_1x05_P2.54mm_Vertical
J13: To LEDS; PinHeader_1x03_P2.54mm_Vertical
U1: FFC [C]; FFC Aliexpress 0.5mm 6P
U2: FFC [U]; FFC Aliexpress 0.5mm 12P
U3: FFC [D]; FFC Aliexpress 0.5mm 18P
U5: FFC [G]; FFC Aliexpress 0.5mm 12P

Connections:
+3V3: J1.1, J10.3, J10.6, U1.3; also elsewhere on the board
+5V: J2.2, J2.3, J3.2, J3.3, J4.7, J5.4, J6.3, J7.1, J8.6, J11.9, J11.10, J11.11, J11.12, J12.3, J13.1, U2.5, U2.8, U3.8, U3.11, U5.5, U5.8
CPU-GPU GPIO 0: J11.3, U5.2
CPU-GPU GPIO 1: J11.4, U5.4
CPU-GPU GPIO 2: J11.17, U5.9
CPU-GPU GPIO 3: J11.18, U5.11
CPU-GPU RX: J11.6, U5.6
CPU-GPU TX: J11.15, U5.7
Disp 0: J9.1, U3.2
Disp 1: J9.3, U3.3
Disp 2: J9.5, U3.4
Disp 3: J9.7, U3.5
Disp 4: J9.9, U3.6
Disp 5: J9.11, U3.7
Disp 6: J9.13, U3.12
Disp 7: J9.2, U3.13
Disp 8: J9.6, U3.14
Disp 9: J9.8, U3.15
Disp 10: J9.10, U3.16
Disp 11: J9.12, U3.17
Disp RX: J9.14, U3.9
Disp TX: J9.15, U3.10
GND: J1.2, J2.1, J2.4, J3.1, J3.4, J4.8, J5.3, J6.4, J7.2, J8.7, J9.4, J9.16, J10.1, J10.2, J10.7, J10.8, J11.1, J11.2, J11.5, J11.7, J11.8, J11.13, J11.14, J11.16, J11.19, J11.20, J12.1, J12.5, J13.3, U1.1, U1.6, U2.1, U2.3, U2.10, U2.12, U3.1, U3.18, U5.1, U5.3, U5.10, U5.12; also elsewhere on the board
unnamed: J12.2, J12.4, J13.2
Snoot SCL: J10.4; also elsewhere on the board
Snoot SDA: J10.5; also elsewhere on the board
TOF SCL: J1.3, U1.5
TOF SDA: J1.4, U1.2
UI 0: J4.1, J7.3, J8.5, U2.2
UI 1: J4.2, J7.4, J8.4, U2.4
UI 2: J4.5, J7.7, J8.3, U2.9
UI 3: J4.6, J8.2, U2.11
UI IO 0: J4.3, J5.2, J6.2, J7.5, J8.1, U2.6
UI IO 1: J4.4, J5.1, J6.1, J7.6, U2.7
XShut: J1.6, U1.4

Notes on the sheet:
VDD GND SCK SDA
VCC GND SCL SDA DC CS RST
BLK CS DC RES SDA SCL VCC GND
GND VDD SCK SDA
Misc Boards - TOF Boards - UI Display Pins to FFC Adapter - Jaw LEDS Board - Mask Sensors - Display Boards - Substructure & Main 20P Pogo Pin Connector
Display
Main-Substructure Pogo Pins
UI Display
TOF Sensors
Mask Sensor
Jaw LEDS


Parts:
C1, C2: 100nF; C_0603_1608Metric_Pad1.08x0.95mm_HandSolder
U4: BME280; Bosch_LGA-8_2.5x2.5mm_P0.65mm_ClockwisePinNumbering

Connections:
+3V3: C1.2, C2.1, U4.2 (CSB), U4.6 (VDDIO), U4.8 (VDD); also elsewhere on the board
GND: C1.1, C2.2, U4.1 (GND), U4.5 (SDO), U4.7 (GND); also elsewhere on the board
Snoot SCL: U4.4 (SCK); also elsewhere on the board
Snoot SDA: U4.3 (SDI); also elsewhere on the board

Board: 2 copper layers, 20 parts (0 on the bottom side), 35 nets, no tracks yet.

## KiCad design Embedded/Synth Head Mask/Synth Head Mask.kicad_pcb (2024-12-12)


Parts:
J1: JST [S]; Molex_PicoBlade_53047-0810_1x08_P1.25mm_Vertical
J2: JST [M]; Molex_PicoBlade_53047-0810_1x08_P1.25mm_Vertical
J3, J4: JST [F]; Molex_PicoBlade_53047-0210_1x02_P1.25mm_Vertical
J5: JST [B]; Molex_PicoBlade_53047-0410_1x04_P1.25mm_Vertical
J6: JST [K]; Molex_PicoBlade_53047-0410_1x04_P1.25mm_Vertical
J7, J8: Misc Expansion; PinHeader_1x03_P2.54mm_Vertical
JP1: LR Select; SolderJumper-3_P1.3mm_Bridged12_RoundedPad1.0x1.5mm
JP2, JP3: Expansion PWR; SolderJumper-3_P1.3mm_Bridged2Bar12_Pad1.0x1.5mm
Q1: BSS138; SOT-23
Q2: AS2302; SOT-23
R2, R3: 10K; R_0603_1608Metric_Pad0.98x0.95mm_HandSolder
U1: FFC [M]; FFC Aliexpress 0.5mm 12P
U2: FFC [S]; FFC Aliexpress 0.5mm 12P

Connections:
+3V3: J1.3, J1.6, J2.3, J2.6, JP1.3 (B), JP2.1 (A), JP3.1 (A), Q1.1 (G), R2.1; also elsewhere on the board
+5V: J5.2, J5.3, J6.2, J6.3, JP2.3 (B), JP3.3 (B), Q2.3 (D), R3.1, U1.5, U1.8, U2.5, U2.8; also elsewhere on the board
CPU IO 0: J7.2, U1.4
CPU IO 1: J8.2, U1.9
Fan PWR: J3.1, J4.1, Q2.2 (S)
GND: J1.1, J1.2, J1.7, J1.8, J2.1, J2.8, J3.2, J4.2, J5.1, J5.4, J6.1, J6.4, J7.3, J8.3, JP1.1 (A), U1.1, U1.2, U1.3, U1.10, U1.11, U1.12, U2.1, U2.12; also elsewhere on the board
unnamed: J2.7, JP1.2 (C)
unnamed: J7.1, JP2.2 (C)
unnamed: J8.1, JP3.2 (C)
unnamed: Q1.3 (D), Q2.1 (G), R3.2
Snoot IO 0: Q1.2 (S), R2.2, U2.4
Snoot RX: U1.6, U2.6
Snoot SCK: J2.4, U2.11
Snoot SCL: J1.4, U2.3
Snoot SD: J2.2, U2.9
Snoot SDA: J1.5, U2.2
Snoot TX: U1.7, U2.7
Snoot WS: J2.5, U2.10

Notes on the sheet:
From Connections (FFC) - CPU to Mask Stuff Connections (JST) - I2S Microphone - 2x Fans - I2C Sensors To Connections - Snoot - CPU to Snoot UART Bypass - PDU Power Bypass from PDU to Snoot (JST)


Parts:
C1, C2: 1uF; R_0603_1608Metric
C3: 10uF; C_0603_1608Metric
U3: AP7366-33W5-7; AP7366

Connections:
+3V3: C2.1, C3.1, U3.5 (Vout); also elsewhere on the board
+5V: C1.1, U3.1 (VCC), U3.3 (EN); also elsewhere on the board
GND: C1.2, C2.2, C3.2, U3.2 (GND); also elsewhere on the board

Board: 2 copper layers, 21 parts (0 on the bottom side), 18 nets, no tracks yet.

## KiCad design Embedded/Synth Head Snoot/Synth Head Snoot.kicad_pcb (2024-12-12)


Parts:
BootSW1: SW_Push; Button-R-667843
C1: 1uF; C_0603_1608Metric
C2: 22uF; C_0603_1608Metric_Pad1.08x0.95mm_HandSolder
C3: 0.1uF; C_0603_1608Metric_Pad1.08x0.95mm_HandSolder
C4: 10uF; C_0603_1608Metric
ESP1: ESP32-S3-WROOM-1; ESP32-S3-WROOM-1U
J1: JST [A]; Molex_PicoBlade_53048-0210_1x02_P1.25mm_Horizontal
J2: 10171746-00021LF; AMPHENOL_10171746-00021LF; PARTREV A
J3: JST [K]; Molex_PicoBlade_53048-0410_1x04_P1.25mm_Horizontal
J4: MSD-1-A; CUI_MSD-1-A; PARTREV 1.0
J5, J6: Touch Pad; PinHeader_1x01_P2.54mm_Vertical
JP1: Gain; SolderJumper-3_P1.3mm_Bridged12_Pad1.0x1.5mm_NumberLabels
L1: MPZ1608S601ATA00; INDC1608X95N
R1, R2: 10K; R_0603_1608Metric
R3, R4: 5.1K; R_0603_1608Metric
TP1, TP2: Touch Pad; TestPoint_Pad_D2.0mm
U1: FFC [S]; FFC Aliexpress 0.5mm 12P
U2: SRV05-4; SOT-23-6
U4: MAX98357AETE_T; QFN50P300X300X80-17N

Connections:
+3V3: C2.1, C3.1, ESP1.2 (3V3), J4.4 (VDD), R1.1, R2.1; also elsewhere on the board
+5V: J3.2, J3.3, JP1.3 (B), U1.5, U1.8, U2.5 (VP), U4.7 (VDD), U4.8 (VDD__1)
/3V3 Regulator/Vin: C4.1, L1.2; also elsewhere on the board
GND: BootSW1.2, C1.1, C2.2, C3.2, C4.2, ESP1.1 (GND), ESP1.40 (GND), ESP1.41 (GND), J2.A1_B12 (GND_A), J2.B1_A12 (GND_B), J3.1, J3.4, J4.6 (VSS), J4.G1 (COVER_GND), J4.G2 (COVER_GND__1), J4.G3 (COVER_GND__2), J4.G4 (COVER_GND__3), JP1.1 (A), R3.2, R4.2, U1.1, U1.12, U2.2 (VN), U4.3 (GND), U4.11 (GND__1), U4.15 (GND__2), U4.17 (EP); also elsewhere on the board
Mic SCK: U1.11
Mic SD: U1.9
Mic WS: U1.10
unnamed: C1.2, ESP1.3 (EN), R1.2
unnamed: BootSW1.1, ESP1.27 (GPIO0/BOOT), R2.2
unnamed: J1.1, U4.10 (OUTN)
unnamed: J1.2, U4.9 (OUTP)
unnamed: J2.A5 (CC1), R4.1
unnamed: J2.B5 (CC2), R3.1
unnamed: J2.A4_B9 (VBUS_A), J2.B4_A9 (VBUS_B), L1.1
unnamed: J6.1, TP2.1
unnamed: JP1.2 (C), U4.2 (GAIN_SLOT)
SD Card CLK: J4.5 (CLK)
SD Card CS: J4.2 (CD/DAT3)
SD Card Detect: J4.CD
SD Card MISO: J4.7 (DAT0)
SD Card MOSI: J4.3 (CMD)
Sensors SCL: U1.3
Sensors SDA: U1.2
Snoot GPIO: U1.4
Snoot TX: U1.7
SnootRX: U1.6
Speaker Enable/Filter: U4.4 (SD_MODE)
Speaker SCK: U4.16 (BCLK)
Speaker SD: U4.1 (DIN)
Speaker WS: U4.14 (LRCLK)
Touch Pad: J5.1, TP1.1
USB +: ESP1.14 (GPIO20/U1CTS/ADC2_CH9/CLK_OUT1/USB_D+), J2.A6 (DP1), J2.B6 (DP2), U2.1 (IO1)
USB -: ESP1.13 (GPIO19/U1RTS/ADC2_CH8/CLK_OUT2/USB_D-), J2.A7 (DN1), J2.B7 (DN2), U2.4 (IO3)

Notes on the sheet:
Capacitive Touch not implemented (Just route the esp32 Touch Pin) Maw Top LED Strip not implemented (Requires Hardware Architecture)
ESP32 S3 Based - Boopable Capacitive Touch Pad (Raised by Pins) - Hall Effect (ESP32 Built In) Stuff - Speaker (Audio Processing and Voice Mod) - Maw Top LEDS Strip Connections - FFC to-from Mask - JST Power from Mask


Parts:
C5, C6: 1uF; R_0603_1608Metric
C7: 10uF; C_0603_1608Metric
U3: AP7366-33W5-7; AP7366

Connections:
+3V3: C6.1, C7.1, U3.5 (Vout); also elsewhere on the board
/3V3 Regulator/Vin: C5.1, U3.1 (VCC), U3.3 (EN); also elsewhere on the board
GND: C5.2, C6.2, C7.2, U3.2 (GND); also elsewhere on the board

Board: 2 copper layers, 27 parts (3 on the bottom side), 16 nets, no tracks yet.

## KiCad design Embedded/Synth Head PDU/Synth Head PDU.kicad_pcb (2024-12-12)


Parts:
C1: 0.1uF; C_0603_1608Metric_Pad1.08x0.95mm_HandSolder
D1: SL54A; D_SMA-SMB_Universal_Handsoldering
F1: BK16-500-SZ; Fuse_Bourns_MF-RHT500
J1: 10171746-00021LF; AMPHENOL_10171746-00021LF; PARTREV A
J2, J3: JST [P]; PinHeader_1x08_P2.54mm_Vertical
J4: JST [USB]; PinHeader_1x06_P1.27mm_Vertical
J5: JST [C]; Molex_PicoBlade_53048-0410_1x04_P1.25mm_Horizontal
J6: JST [B]; Molex_PicoBlade_53048-0410_1x04_P1.25mm_Horizontal
J7: JST [G]; PinHeader_1x08_P2.54mm_Vertical
Q1, Q2: RQ3E100BNTB; TRANS_RQ3E100BNTB; PARTREV B
R1, R2: 5.1K; R_0603_1608Metric
R3, R4: 4K; R_0603_1608Metric_Pad0.98x0.95mm_HandSolder
R5: 10K; R_0603_1608Metric
R6: 1K; R_0603_1608Metric_Pad0.98x0.95mm_HandSolder
R7, R9: 12K; C_0603_1608Metric_Pad1.08x0.95mm_HandSolder
R8, R10: 3K; C_0603_1608Metric_Pad1.08x0.95mm_HandSolder
R11, R12: 10K; R_0603_1608Metric_Pad0.98x0.95mm_HandSolder
U1: FFC [K]; FFC Aliexpress 0.5mm 6P
U2: TMCS1108A2BQDR; SOIC-8_3.9x4.9mm_P1.27mm
U4: RSC002P03
U5: ADS1015IDGS; TSSOP-10_3x3mm_P0.5mm
VR1, VR2: LM1084IT-5.0_NOPB; TO254P1054X470X1955-3; PARTREV G

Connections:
+3V3: C1.1, R11.1, R12.1, U2.8 (VS), U5.8 (VDD); also elsewhere on the board
+5V: J5.2, J5.3, J6.2, J6.3, J7.3, J7.4, J7.5, J7.6, U2.3 (Output), U2.4 (Output)
Analog Current: U2.7 (Vout), U5.5 (AIN1)
Analog Voltage: R3.2, R4.1, U5.4 (AIN0)
Fin Batt Voltage 0: R7.2, R8.1, U5.6 (AIN2)
Fin Batt Voltage 1: R9.2, R10.1, U5.7 (AIN3)
GND: C1.2, J1.A1_B12 (GND_A), J1.B1_A12 (GND_B), J1.SH1 (SHIELD), J1.SH2 (SHIELD__1), J1.SH3 (SHIELD__2), J1.SH4 (SHIELD__3), J2.1, J2.2, J2.7, J2.8, J3.1, J3.2, J3.7, J3.8, J4.1, J4.6, J5.1, J5.4, J6.1, J6.4, J7.1, J7.2, J7.7, J7.8, R1.2, R2.2, R4.2, R5.2, R8.2, R10.2, U1.1, U1.6, U2.5 (GND), U5.1 (ADDR), U5.3 (GND), VR1.1 (ADJ/GND), VR2.1 (ADJ/GND); also elsewhere on the board
unnamed: D1.1 (K), F1.1
unnamed: J1.A5 (CC1), R2.1
unnamed: J1.B5 (CC2), R1.1
unnamed: Q1.4, Q2.4, R5.1, U4.3 (D)
unnamed: R6.2, U4.1 (G)
unnamed: Q1.1_3, VR1.3 (INPUT)
unnamed: Q2.1_3, VR2.3 (INPUT)
PWR: F1.2, R3.1, U2.1 (Input), U2.2 (Input), VR1.2 (OUTPUT), VR2.2 (OUTPUT); also elsewhere on the board
Raw PWR 0: J2.3, J2.4, J2.5, J2.6, Q1.5_8, R7.1
Raw PWR 1: J3.3, J3.4, J3.5, J3.6, Q2.5_8, R9.1
SCL: R11.2, U1.5, U5.9 (SDA)
SDA: R12.2, U1.2, U5.10 (SCL)
USB +: J1.A6 (DP1), J1.B6 (DP2), J4.3, U1.3
USB -: J1.A7 (DN1), J1.B7 (DN2), J4.4, U1.4
USB PWR: D1.2 (A), J1.A4_B9 (VBUS_A), J1.B4_A9 (VBUS_B), J4.2, J4.5, R6.1, U4.2 (S)

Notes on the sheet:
FFC - 2x BMS - PDU to CPU Comms Link From Connections (JST) - 2x Fin Pogo Connectors - USBC (1x Cable) To Connections (JST) - CPU: 1A - GPU: 12A - Mask Board: 1.5A Feats - Voltage Sense: MCU ADC - Current Sense: TMCS1108A2BQDR


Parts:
C2, C3: 1uF; R_0603_1608Metric
C4: 10uF; C_0603_1608Metric
U3: AP7366-33W5-7; AP7366

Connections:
+3V3: C3.1, C4.1, U3.5 (Vout); also elsewhere on the board
GND: C2.2, C3.2, C4.2, U3.2 (GND); also elsewhere on the board
PWR: C2.1, U3.1 (VCC), U3.3 (EN); also elsewhere on the board

Board: 2 copper layers, 34 parts (4 on the bottom side), 22 nets, no tracks yet.

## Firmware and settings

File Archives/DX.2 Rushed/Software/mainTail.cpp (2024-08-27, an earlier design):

#include <Arduino.h>
#include <ESP32_Servo.h>
#include <Wire.h>
#include <HardwareSerial.h>
#include <Adafruit_MPU6050.h>
#include <Adafruit_Sensor.h>

Adafruit_MPU6050 mpu;
Servo TailServos[4];
// HardwareSerial fromTransmitter(2);
int ServoPins[] = {19, 18, 5, 17};

const int numReadings = 10;  // Number of readings to include in the moving average
float gyroXReadings[numReadings];
float gyroYReadings[numReadings];
int gyroXIndex = 0;
int gyroYIndex = 0;
const float gyroThreshold = 2.0;  // Threshold to reject small noise

void addToMovingAverage(float *readings, int &index, float newValue) {
    readings[index] = newValue;
    index = (index + 1) % numReadings;
}

float calculateMovingAverage(float *readings) {
    float sum = 0;
    for (int i = 0; i < numReadings; i++) {
        sum += readings[i];
    }
    return sum / numReadings;
}

const int centerPosition1 = 120;
const int centerPosition2 = 120;
const int centerPosition0 = 150;
const int centerPosition3 = 150;

void moveServo(Servo &servo, int centerPosition, int offset) {
    int targetPosition = centerPosition + offset;
    servo.write(targetPosition);
    delay(10);  // Delay for smoother motion
}


void setup() {
    Serial.begin(115200);
    Wire.begin(16, 4);
    for (size_t i = 0; i < 4; i++) {
        TailServos[i].attach(ServoPins[i]);
    }
    // fromTransmitter.begin(115200, SERIAL_8N1, 22, 21);

    if (!mpu.begin()) {
        Serial.println("Failed to find MPU6050 chip");
        while (1);
    }

    mpu.setAccelerometerRange(MPU6050_RANGE_2_G);
    mpu.setGyroRange(MPU6050_RANGE_250_DEG);

}

// unsigned long lastCheckTime = 0;
// const unsigned long checkInterval = 10000;
// unsigned long currentTime;
// void PingEverySecond(){
//     currentTime = millis();
//     if(currentTime - lastCheckTime >= checkInterval){
//         fromTransmitter.begin(115200, SERIAL_8N1, 21, 22);
//         lastCheckTime = currentTime;
//     }
// }

int Idle = 0;
int Mode = 1;
int Restart = 0;
void loop() {
    sensors_event_t a, g, temp;
    mpu.getEvent(&a, &g, &temp);

    // PingEverySecond();

    // if(fromTransmitter.available()){
    //     float idle, mode, restart;
    //     String buffer = fromTransmitter.readStringUntil('\n');
    //     sscanf(buffer.c_str(), "%f %f %f", &idle, &mode, &restart);
    //     Idle = static_cast<int>(idle);
    //     Mode = static_cast<int>(mode);
    //     Restart = static_cast<int>(restart);
    // }
    // Serial.print(Idle);
    // Serial.print(" ");
    // Serial.print(Mode);
    // Serial.print(" ");
    // // Serial.println(Restart);
    // Serial.print(digitalRead(22));
    // Serial.print(" ");
    // Serial.print(digitalRead(21));
    // Serial.println("");

    if(1){
        switch(1){
            case 0: // Wag
                TailServos[2].write(150);
                TailServos[1].write(150);
                for(signed int i = -45; i <= 45; i++){
                    TailServos[0].write(120 + i);
                    TailServos[3].write(120 - i*2);
                    delay(5);
                }
                for(signed int i = 45; i >= -45; i--){
                    TailServos[0].write(120 + i);
                    TailServos[3].write(120 - i*2);
                    delay(5);
                }
                break;
            case 1: // Gyro
                // Serial.println(g.gyro.z);
                TailServos[0].write(120 + g.gyro.z * 15);
                TailServos[3].write(120 - g.gyro.z * 25);
                break;
            default:
                break;
        }
    }
    // if(Restart){
    //     Serial.print("ESP Restarting...");
    //     TailServos[2].write(150);
    //     TailServos[1].write(150);
    //     TailServos[0].write(120);
    //     TailServos[3].write(120);
    //     ESP.restart();
    // }
    // Serial.println(g.gyro.z);


    // Move servo 1 and 2 (center position: 120 degrees) in opposite directions
    // for(signed int i = -45; i <= 45; i++){
    //     TailServos[2].write(120 + i);
    //     TailServos[1].write(120 - i*2);
    //     delay(20);
    // }
    // for(signed int i = -45; i <= 45; i++){
    //     TailServos[3].write(150 + i);
    //     TailServos[0].write(150 - i*2);
    //     delay(20);
    // }
    // for(signed int i = 45; i >= -45; i--){
    //     TailServos[2].write(120 + i);
    //     TailServos[1].write(120 - i*2);
    //     delay(20);
    // }
    // for(signed int i = 45; i >= -45; i--){
    //     TailServos[3].write(150 + i);
    //     TailServos[0].write(150 - i*2);
    //     delay(20);
    // }

}

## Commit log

2024-08-27 General Update
    [DX Visor Buck.step, Rubber Holder V3.step, Subsurface Jaw Joint V3.step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]
2024-12-04 Finished electrical overview schematic
2024-12-05 Updated which electronic components were placed in the CAD
2024-12-05 Preparing Datasheets & KiCAD Projects
    [Synth Head CPU.kicad_pcb, Synth Head CPU.kicad_sch, Synth Head GPU.kicad_pcb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]
2024-12-06 Mask Board & Snoot Ports Defined
2024-12-06 Added Dedicated Power Connections Map
2024-12-06 KiCAD Summaries, Connections & Feature Descriptions
    [Synth Head BMS.kicad_pcb, Synth Head BMS.kicad_sch, Synth Head GPU.kicad_sch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]
2024-12-06 Added PCBs & Schematics to DX.3 (Rushed)
    [DX.3R.kicad_pcb, DX.3R.kicad_sch]
2024-12-06 Added some component selection in KiCAD
    [Synth Head CPU.kicad_sch, Synth Head GPU.kicad_sch]
2024-12-07 KiCAD Added the schematics to drive some sensors
    [BME280.kicad_sch, ICM20948.kicad_sch, MCP7940N-SN.kicad_sch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]
2024-12-07 Some Sensors Added to the GPU and CPU
    [BME280.kicad_sch, ICM20948.kicad_sch, Synth Head CPU.kicad_sch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]
2024-12-07 Majority of the pins for the Mask Board & Snoot Added
    [Synth Head CPU.kicad_sch, Synth Head GPU.kicad_sch, Synth Head Mask.kicad_sch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]
2024-12-08 Added Cable Lengths to the Connections Diagram
2024-12-08 Cable Management for the Circuit Boards
2024-12-08 Added Power and USBC to GPU
    [1V8 Reg.kicad_sch, 3V3 Reg.kicad_sch, 5V Reg.kicad_sch]
2024-12-08 GPU Port Assignments & Sensors Confirmed
    [1V8 Reg.kicad_sch, 3V3 Reg.kicad_sch, Synth Head GPU.kicad_sch]
2024-12-08 CPU Power & USB C Port Added
    [1V8 Reg.kicad_sch, 3V3 Reg.kicad_sch, Synth Head CPU.kicad_sch]
2024-12-08 CPU FFC Ports Added
    [Synth Head CPU.kicad_sch]
2024-12-09 Added I2C GPIO Expansion to GPU & Some Pin Position Updates
    [Synth Head CPU.kicad_sch, Synth Head GPU.kicad_sch]
2024-12-09 Added Voltage Buffer & Modified Sheet Hierarchy
    [Neo-M7.kicad_sch, Synth Head CPU.kicad_sch]
2024-12-09 Added Speaker, Power & USB C to Snoot Board
    [3V3 Reg.kicad_sch, Synth Head Snoot.kicad_sch]
2024-12-09 Nearly completed Mask Board
    [3V3 Reg.kicad_sch, Synth Head Mask.kicad_sch, Synth Head Snoot.kicad_sch]
2024-12-09 Added Touch Pad to Snoot
    [Synth Head Snoot.kicad_sch]
2024-12-10 Added GPS RF Port
    [Neo-M7.kicad_sch, Synth Head CPU.kicad_sch]
2024-12-10 Added Indicator Power LEDS & some Decoupling Caps
    [Synth Head GPU.kicad_sch]
2024-12-10 Added Power Indicator LEDS & Decoupling Caps
    [Synth Head CPU.kicad_sch]
2024-12-10 PDU Schematic Basically Completed
    [3V3 Reg.kicad_sch, Synth Head PDU.kicad_sch]
2024-12-10 PDU Nearly Complete
    [Synth Head BMS.kicad_sch, Synth Head PDU.kicad_sch]
2024-12-11 Added Jaw LEDS
    [Synth Head CPU.kicad_sch]
2024-12-11 Prepared All Main Boards for PCB Creation
    [BME280.kicad_sch, ICM20948.kicad_sch, MCP7940N-SN.kicad_sch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]
2024-12-11 Added Misc Boards & Adapters
    [BME280.kicad_sch, Misc Circuits & Adapters.kicad_pcb, Misc Circuits & Adapters.kicad_sch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]
2024-12-12 Prepared Circuits for Routing and Placement Tuning
    [MCP7940N-SN.kicad_sch, Misc Circuits & Adapters.kicad_pcb, Misc Circuits & Adapters.kicad_sch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]
2024-12-12 CPU PCB Done
    [Synth Head CPU.kicad_pcb, Synth Head CPU.kicad_sch]
2024-12-13 GPU Routed All but pins to ESP32
    [Synth Head GPU.kicad_pcb]
2024-12-14 Test Update
    [Synth Head GPU.kicad_sch]
